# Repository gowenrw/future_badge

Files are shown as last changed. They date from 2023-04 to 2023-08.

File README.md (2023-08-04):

# future_badge

Future Badge Artifacts

This is a DEFCON Indie badge created for DC31.

This is where all the files for the Future Badge will be stored.

This includes code and art and cad and fab files.  All the things.

## File Structure

This is the file structure of this repository

* [/](/README.md) - YOU ARE HERE
* [/art/](./art/) - Artwork and other graphics created by this project
  * [/art/inspiration/](./art/inspiration/) - Art and graphics pulled from other sources used as inspiration for this project
  * [/art/fonts/](./art/fonts/) - Fonts used in art and graphics
* [/code/](./code/) - All project related Code / Firmware
* [/docs/](./docs/) - Documentation created by this project including web pages
* [/eda/](./eda/) - Electronic Design Automation files (i.e. KiCad)
  * [/eda/future_badge/](./eda/future_badge/) - KiCad 6.x project folder for the future_badge PCB
* [/reference_parts/](./reference_parts/) - Documentation pulled from other sources related to components
* [/README.md](/README.md) - This File
* [/LICENSE](/LICENSE) - Currently set to MIT

Note: the reference_parts directory is a link to a submodule repository.
To add it use the following cmd after cloning this:
```
git submodule add https://github.com/gowenrw/reference_parts reference_parts
```
This will make a link to the current commit of that repo.
To update it to a newer commit after its been added use this cmd:
```
git submodule update --init --recursive
```

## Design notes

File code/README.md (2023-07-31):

# Code

This is where all the project related Code / Firmware is located

# File Structure

This is the file structure of this repository

* [/](/README.md) - Home
* [/code/](/code/) - YOU ARE HERE

# Arduino IDE/CLI

The code presented here is mostly Arduino code.

In order to use this code and push new code to the ESP32 on the badge we recommend using the Arduino IDE/CLI software.
This can be downloaded for various platforms at [arduino.cc](https://www.arduino.cc/en/software).

The Arduino IDE UI will require some manual configuration to work with the badge ESP32 and our code.

The Arduino CLI can be used instead and allows for scripting much of the initial setup and use of whichever IDE you like (in my case I use VSCode).

# Arduino Versions

These are the Arduino IDE and CLI versions we have tested the code with:

* Arduino IDE v 2.1.1
  * [Windows MSI DL Link](https://downloads.arduino.cc/arduino-ide/arduino-ide_2.1.1_Windows_64bit.msi)
  * [Linux 64bit AppImage](https://downloads.arduino.cc/arduino-ide/arduino-ide_2.1.1_Linux_64bit.AppImage)
  * [Installation Instructions](https://docs.arduino.cc/software/ide-v2/tutorials/getting-started/ide-v2-downloading-and-installing)
* Arduino CLI v 0.32.3
  * [Windows MSI DL Link](https://github.com/arduino/arduino-cli/releases/download/0.32.3/arduino-cli_0.32.3_Windows_64bit.msi)
  * [Linux 64bit Tarball Link](https://github.com/arduino/arduino-cli/releases/download/0.32.3/arduino-cli_0.32.3_Linux_64bit.tar.gz)
  * [Installation Instructions](https://arduino.github.io/arduino-cli/0.32/installation/)

# Quickstart

If you want to jump right in and start compiling and uploading code using the Arduino CLI and the scripts provided then checkout the [QUICKSTART page](QUICKSTART.md).

# Arduino IDE setup and use

Some additional setup is required to use the Arduino IDE with the ESP32 on the badge:

* Add the ESP32 boards manager URL in preferences
  * Under File->Preferences find the "Additional boards manager URLs" section and add the following
  * https://espressif.github.io/arduino-esp32/package_esp32_index.json
  * Then click OK and close the IDE.  When it is reopened it wil download the ESP32 board definitions.
* Select the board "ESP32 Dev Module"
  * You need to select a board to associate with the code even if that board is not connected
  * In the "Select Board" dropdown, choose "ESP32 Dev Module" from the list
  * The first time you do this it may download some addiotional software.
* Connect the ESP32 via USB cable and select the COM port if it is not autodetected
  * In most cases it should autodetect the port
  * Sometimes on first connect you need to help it by going to Tools->Port and choosing the port
* This code exceeds the normal partition size so make sure you select the Minimal SPIFFS Partition type
  * This setting can be found under Tools -> Partition Scheme
* This code uses the AdaFruit NeoPixel library which needs to be installed
  * The library can be installed via the Arduino IDE library manager or manually
  * Installation instructions can be found at [the adafruit neopixel github page](https://github.com/adafruit/Adafruit_NeoPixel)

Once the Arduino IDE environment has been set up you can simply open one of the sketches here, make whatever changes you like, then compile and upload the code to the badge.

# Arduino CLI

In an effort to bring portability to the code here (since this is lacking in the Arduino 2.x IDE) we will be providing a local configuration file for the Arduino CLI and scripts to make use of it.

While we cannot ensure this will work on all systems, the files provided should at a minimum help you configure your local environment.

## Using the CLI Local Config

The arduino cli will use a global default config if a config file is not specified.

A local config file is provided named ```arduino-cli.yml``` which uses relative path references for the data and staging and build and user area that Arduino CLI should use.

These directories are local to the repository code directory and the CLI will install all its needed files here instead of in the various places it usually defualts to on differnt systems.

While this might duplicate many files on your system if they are already installed in default locations, it provides a consistent cross platform way of knowing exactly what libraries, headers, etc., that Arduino will use in the compilation of your code.

NOTE that the .gitignore for this repository has been set up to ignore the local directories used to store the core and library files to prevent these files from accidentally getting uploaded to github.

To use the Arduino CLI with this local config file simply add the ```--config-file arduino-cli.yml``` argument to each CLI command.

For example, the command below uses the local config file and will dump the current config to the screen
```
arduino-cli --config-file arduino-cli.yml config dump
```

## Setup for CLI

There are a few things that need to be done to setup the Arduino CLI for use with the badge ESP32 and our code.

The ESP32 board core files must be loaded as well as any libraries the code will use.

To simplify this setup we have created setup bash script named ```cli-setup.sh``` that can be run on Linux and Windows (via Git Bash for Windows).

To perform the CLI setup via the script execute it in the code directory
```
bash ./cli-setup.sh
```

This script will save any std_out and std_err output to a file named ```arduino_cli_setup.log``` which you can review if you are having issues.

To perform the CLI setup manually without this script you can use the commands outlined below.

### Installing the ESP32 board core for CLI

Since the config is specifying a third party core for the ESP32 we need to pull an initial index from it.  This search command will pull that index.
```
arduino-cli --config-file arduino-cli.yml core search esp32
```

Next we need to install the ESP32 board core files using this command.
```
arduino-cli --config-file arduino-cli.yml core install esp32:esp32
```

If the ESP32 board core files were already installed the above will simply say already installed.

To update the core file indexs to check for newer versions of previously installed cores, use the following command
```
arduino-cli --config-file arduino-cli.yml core update-index
```

To upgrade any previously installed cores use the following command
```
arduino-cli --config-file arduino-cli.yml core upgrade
```

### Installing the Neopixel Library

This code uses the AdaFruit NeoPixel library which needs to be installed

If this is the first time we are installing a library we will need the indexes so this search command will get them
```
arduino-cli --config-file arduino-cli.yml lib search 'Adafruit NeoPixel'
```

Next we need to install the Adafruit NeoPixel library files with this command
```
arduino-cli --config-file arduino-cli.yml lib install 'Adafruit NeoPixel'
```

If the Adafruit NeoPixel library files were already installed the above will simply say already installed.

To upgrade a previously installed version of this library use the following command
```
arduino-cli --config-file arduino-cli.yml lib upgrade 'Adafruit NeoPixel'
```

### Installing Other Libraries

In addition to the Neopixel Library above the CTF portion of our code requires a few more libraries.

These should be installed using the same steps as above.

This is the list of additional libraries needed

* "AsyncTCP"
* "ESPAsyncWebSrv"
* "DNSServer"

## Connect badge ESP32 board via CLI

The following command will dump a list of all available board cores installed
```
arduino-cli --config-file arduino-cli.yml board listall
```

Make sure the ESP32 we are using on the badge is in that list
```
  ESP32 Dev Module                 esp32:esp32:esp32
```

If it is not then retry the CLI setup to install the core files.

Next we will connect the badge ESP32 to our machine using a USB C cable
and check if the CLI can see it.

The following command will list all the connected boards the CLI sees
```
arduino-cli --config-file arduino-cli.yml board list
```

This will show the detected COM port and board type (which may be Unknown)
```
  Port Protocol Type                Board Name FQBN Core
  COM4 serial   Serial Port (USB)   Unknown
```

Don't worry if the board FQBN shows up as Unknown since we can set that

Take note of the COM port since we will need that to communicate with it later

## Compile code via CLI

At this point we should be ready to compile and upload code to the badge ESP32 board.

In the following examples we will be referencing the sketch ```future_badge_rev02``` code so you will need to change this for whichever sketch you wish to use.

The following command will compile the named sketch for use with our board fqbn
```
arduino-cli --config-file arduino-cli.yml compile --fqbn esp32:esp32:esp32 --build-path _build --export-binaries future_badge_rev02 --build-property build.partitions=min_spiffs --build-property upload.maximum_size=1966080
```

The arg ```--build-path _build``` is optional to have it put all build artifacts here instead of temp for ease of troubleshooting.

The arg ```--export-binaries``` will save the final binary files into ```<sketch_name>/build/<fqbn>/``` for use by upload.

The build property args ```--build-property build.partitions=min_spiffs --build-property upload.maximum_size=1966080``` make sure that the partition size and upload size are set properly.
Our code is THIC and wont fit in the default partition size.

When the CLI compile is run it should show you compile stats and/or errors similar to this
```
  Sketch uses 1827197 bytes (92%) of program storage space. Maximum is 1966080 bytes.
  Global variables use 48884 bytes (14%) of dynamic memory, leaving 278796 bytes for local variables.
  Maximum is 327680 bytes.
  Used library        Version Path
  Adafruit NeoPixel   1.11.0  .\code\libraries\Adafruit_NeoPixel
  WiFi                2.0.0   .\code\_data\packages\esp32\hardware\esp32\2.0.11\libraries\WiFi
  future_badge_ctf_r2 1.2.0   .\code\libraries\future_badge_ctf_r2
  AsyncTCP            1.1.4   .\code\libraries\AsyncTCP
  DNSServer           2.0.0   .\code\_data\packages\esp32\hardware\esp32\2.0.11\libraries\DNSServer
  ESPAsyncWebSrv      1.2.6   .\code\libraries\ESPAsyncWebSrv
  FS                  2.0.0   .\code\_data\packages\esp32\hardware\esp32\2.0.11\libraries\FS
  Used platform Version Path
  esp32:esp32   2.0.11  .\code\_data\packages\esp32\hardware\esp32\2.0.11
```

### Script to Compile code via CLI

To simplify the above we have created a bash script named ```cli-compile.sh``` that takes a single command line argument of the sketch name.

To perform the compile via the script execute it in the code directory
```
bash ./cli-compile.sh future_badge_rev02
```

## Upload code via CLI

Now we are ready to upload the binary we compiled to the badge ESP32 board.

Note that the binary file needed is saved to ```<sketch_name>/build/<fqbn>/``` and will be named ```<sketch_name>.ino.bin```
The code we have written here may include binaries which can be used without compiling and if you make changes and compile then these files should be overwritten.

The following command will upload the named sketch binary to the badge
```
arduino-cli --config-file arduino-cli.yml upload -p COM4 --fqbn esp32:esp32:esp32 --input-file future_badge_rev02/build/esp32.esp32.esp32/future_badge_rev02.ino.bin
```

NOTE: Saving the compiled binary in a defined place and uploading from an input file allows for quickly changing between different code without the need to compile each again.

It should show you upload stats and/or errors
```
  esptool.py v4.5.1
  Serial port COM4
  Connecting....
  Chip is ESP32-D0WD-V3 (revision v3.0)
  Features: WiFi, BT, Dual Core, 240MHz, VRef calibration in efuse, Coding Scheme None
  Crystal is 40MHz
  MAC: a8:42:e3:47:f0:50
  Uploading stub...
  Running stub...
  Stub running...
  Changing baud rate to 921600
  Changed.
  Configuring flash size...
  Flash will be erased from 0x00001000 to 0x00005fff...
  ...
  Compressed 18960 bytes to 13073...
  Writing at 0x00001000... (100 %)
  Wrote 18960 bytes (13073 compressed) at 0x00001000 in 0.3 seconds (effective 538.9 kbit/s)...
  Hash of data verified.
  ...
  Compressed 732656 bytes to 475614...
  Writing at 0x00010000... (3 %)
  Writing at 0x0001c1bd... (6 %)
  ...
  Writing at 0x000bcec0... (96 %)
  Writing at 0x000c2b72... (100 %)
  Wrote 732656 bytes (475614 compressed) at 0x00010000 in 6.3 seconds (effective 925.8 kbit/s)...
  Hash of data verified.
  Leaving...
  Hard resetting via RTS pin...
```

### Script to Upload code via CLI

To simplify the above we have created a bash script named ```cli-upload.sh``` that takes two command line arguments of the sketch name and serial port.

To perform the compile via the script execute it in the code directory
```
bash ./cli-upload.sh future_badge_rev02 COM4
```

## Monitor Serial Output

To monitor the serial output you can use the arduino-cli or your favorite serial app.

The following command will list all the connected boards so you can get the serial port
```
arduino-cli --config-file arduino-cli.yml board list
```

The arduino-cli monitor command with serial port (from above) and baud config can be used like this:
```
arduino-cli monitor --port COM4 --config baudrate=115200
```

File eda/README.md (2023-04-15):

# Electronic Design Automation

This is where all the Electronic Design Automation files for the PCB(s) will be stored.
The EDA used is KiCad 6.x unless otherwise specified.

## File Structure

This is the file structure of this repository

* [/](/README.md) - Home
* [/eda](/eda/) - YOU ARE HERE
  * /eda/<eda_project>/ - KiCad project folder for the named project PCB(s)
    * ./3d_models/ - This directory contains footprint 3d model files
    * ./gerber/ - This directory contains gerber formatted files for manufacturing
    * ./lib_fp/ - This directory contains footprint module directories
    * ./lib_sh/ - This directory contains schematic library files
    * ./snapshots/ - This directory contains prints of schematic / cad files and images of preview / final product

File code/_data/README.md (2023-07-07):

# _data

This diretory is used to store arduino cli created files.

This file ensures the creation of the directory locally.

The gitignore should prevent any other files here getting sent to the repo.

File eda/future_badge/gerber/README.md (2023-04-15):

# gerber

This directory is for the gerber formatted files to be sent to manufacturing

Subdirectories named by date in YYYY-MM-DD format contain the gerber files generated on that date.

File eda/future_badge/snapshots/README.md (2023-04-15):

# snapshots

This directory contains prints of schematic / cad files and images of preview / final product

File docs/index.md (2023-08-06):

---
layout: default
---

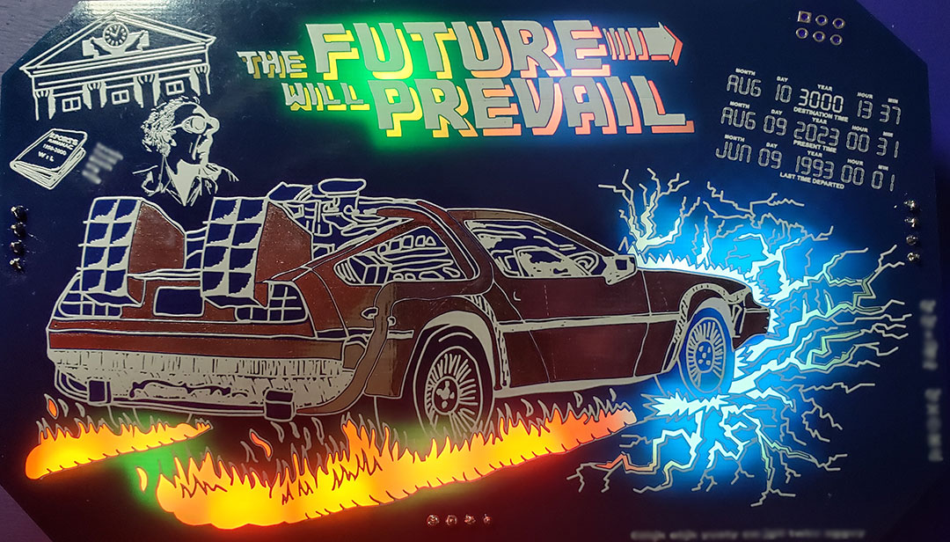
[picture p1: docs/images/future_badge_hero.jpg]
future badge hero


# Welcome

Welcome to the future badge website/repository.

This is where you will find all the details and files and instructions related to my DC31 future badge #badgelife.

The idea for this badge came from the DEFCON 31 theme: "The Future Will Prevail".
This theme made me think of the Back to the Future movies and the famous time traveling DeLorean.

This badge is mostly being provided as a DIY solder kit with a small quantity being provided fully assembled.
If you are looking for instructions on how to assemble the kit then you have come to the right place.

I hope that everyone who gets one of these badges enjoys it.  It was made with love for everyone in the community to enjoy.  And as with all my badges, it is all open hardware/software with all files provided in this repository.  So, if you didn't have a chance to get one of these kits at the con you can always make your own.

-- [@alt_bier](https://twitter.com/alt_bier)  - [My Contact Info](https://gowen.net/about)

---

# Sponsors

I want to thank all of our sponsors from the Indiegogo campaign that made this badge possible.

[Click this link to see the sponsor list.](future_badge_sponsors.md)

# Kit Assembly

Assembly Instructions for the Future Badge kit can be found here: [Badge Assembly](future_badge_assembly.md)

An assembly walkthrough video can be found here:
[Future Badge Soldering Walk-Through Video](https://youtu.be/ozqXjqQztUM)

# Details

As stated in the welcome, the idea for this badge came from the DEFCON 31 theme: "The Future Will Prevail".
This theme made me think of the Back to the Future movies and the famous time traveling DeLorean.
Having done a car on a previous badge (Godzilla vs Bladerunner) I saw this as an opportunity to improve on that by making the car capacitive touch sensitive and the fact that the DeLorean in the BTTF movies was metalic silver made this a perfet fit.

In keeping with the theme I wanted to make the badge look like a BTTF movie poster and shape it like a movie ticket.
I think the final design was sucessful on both accounts.

I made a design choice to use back lit solder mask voids and two PCBs to sandwich the components hiding them and highlighting the art.
Having seen other groups do these things so sucessfully in the past (looking at you DC540!) I wanted to tackle this and I think it turned out great.

Since I had not used an ESP on a badge yet I decided to use the ESP32 on this one.
One of the cool things about the ESP32 is the built in wireless.
So, we are planning on making use of that with an embedded CTF challenge (if we can get the code working in time LOL)

Speaking of challenges, this badge includes some crypto challenges right on the front silkscreen art.
Nothing too difficult, but a fun feature that will be used in the code based challenge.

In keeping with my goal of making the badge code accessible to people I decided to use Arduino code for this badge.
This presented its own set of challenges as Arduino code it not nativley very mobile and requires lots of local config to match an environment.
I came up with a fix for this by using the Arduino CLI instead of the IDE and using a locally provided config file and scripts for setup, compile, and upload.
See the code readme file for details.

The final design choice that I do have some regrets about is the use of a 9V battery.
I thought it would be cool since many Arduino and other dev board projects use a 9V but I don't recall ever seeing one on a badge.
I know now why 9V batteries are not used on badges.
I was warned to change it but was too far along the development path to do so.
My first prototype board only lasted about 2 hours on a 9V with the wifi off.
Thanks to true from the Whiskey Pirate Crew I was able to get a voltage regulator circuit added that now makes the badge run for 7 to 8 hours on a 9V.
Still not ideal and I'll be providing two 9V batteries in each kit and have lots of spares at defcon to compensate.
But it looks cool right?

# Code

The code is detailed in the github repo which can be found here: [Code Documentation](https://github.com/gowenrw/future_badge/blob/main/code/README.md)

The CTF challenge is a compiled library so you won't gain any hints there.
That source code will be released after defcon.

The rest of the code is open to see and modify as you will.

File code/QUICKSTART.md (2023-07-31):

# Code Quickstart

Notes:

* You will need Arduino CLI Installed and a Bash shell (on Windows Git Bash is provided by Git for Windows)
* The CTF code is a precompiled library so you cant change that for now, source to be released after defcon
* The current code that is loaded on the badge is the sketch named ```future_badge_rev02```

## Setting up Arduino CLI environment

Follow these steps:

* Change directory to the code directory if you arent already there
* Run the following command preceding it with ```bash``` if needed by your OS
  * ```./cli-setup.sh```
* If it completes without errors then setup is complete
  * If you have errors then refer to the main README doc or script file to try the steps manually

## Compiling Code

Once you have made whatever changes you wanted to the code here is how we compile it.

* Change directory to the code directory if you arent already there
* Run the following command preceding it with ```bash``` if needed by your OS changing the sketch name if needed
  * ```./cli-compile.sh future_badge_rev02```
* If it completes without errors then the compile is complete
  * If you have errors then read what they are and make the appropriate changes to your code

## Upload Code

Once the code has been compiled we can upload it to the badge.

Follow these steps:

* Change directory to the code directory if you arent already there
* Run the following command
  * ```arduino-cli --config-file arduino-cli.yml board list```
* Take note of the serial port name of the connected board 
* Run the following command preceding it with ```bash``` if needed and changing the serial port to above
  * ```./cli-upload.sh future_badge_rev02 COM6```

## Serial Monitor

Once the code has been uploaded you can use the serial monitor to look for any text the code is sending.

* Run the following command changing the serial port to what board list showed above
  * ```arduino-cli monitor --port COM6 --config baudrate=115200```

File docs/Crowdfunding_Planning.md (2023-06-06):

# Crowdfunding Planning

Notes about Crowdfunding planning.

## Which Platform

Kickstarter vs Indigogo

Both have similar features.  However, kickstarter seems to have several built in delays.

Both require funding identity verification but kickstarter has a 1-3 business day review period before launch.

Going to set up on both platforms and fastest to be ready to launch will win.

Update: Indigogo won!

https://igg.me/at/future-badge

## Basics

* Campaign Title
  * Future Badge: Wearable Art DEFCON #Badgelife
* Campaign Tagline
  * Future Badge is a wearable piece of electronic art manufactured into a badge themed for DEFCON 31.
* Campaign Card Image
  * Created a 640x640 image
  * [future_badge_campaign_card-1](art/future_badge_campaign_card-1.jpg)
* Images/Video
  * Initial images of concept art and kicad
  * Link to the future badge diaries youtube playlist (Watch progress being made week by week)
* Campaign
  * Submit on Saturday 6/3
  * Launch prior to June DHA if possible
  * Campaign will last 30 days closing first week of July.

## Funding

* Goal is $5000
* Pricing
  * $10 - No-Limit - Buy us a Beverage (No Reward)
  * $60 - Limit 120 - Future Badge Kit
  * $100 - Limit 30 - Future Badge Assembled
* Streach Goal is $7000
  * If the streach goal is met then an SAO addon badge will be created
  * This SAO will be included as a reward for the $60 and $100 support tiers

## Rewards

* The $10 support tier
  * Just a tip with no reward
* The $60 support tier
  * A ticket to pick up a Future Badge Kit (DIY soldering and assembly required)
  * If streach goal met then this ticket will also include an SAO addon
  * Sponsors at this level will receive a digital ticket which entitles them to pick up a Future Badge Kit at one of the badge distributions.
  * The Future Badge Kit is a DIY kit with soldering and assembly required using the components and instructions provided.
  * The Future Badge is a wearable piece of electronic art manufactured in the style of a conference badge themed for the Defcon 31 conference.
  * The badge features an ESP32 controller, at least 16 LEDs including 4 neopixels, capacitive touch, awesome artwork, hackable Arduino code, custom lanyard, and more.
  * Sponsors are responsible for picking up their product at one of the distribution locations/dates/times listed.
* The $100 support tier
  * A ticket to pick up a Fully Assembled Future Badge (No assembly required)
  * If streach goal met then this ticket will also include an SAO addon
  * Sponsors at this level will receive a digital ticket which entitles them to pick up a Fully Assembled Future Badge at one of the badge distributions.
  * The Fully Assembled Future Badge is ready to wear with no assembly required.
  * The Future Badge is a wearable piece of electronic art manufactured in the style of a conference badge themed for the Defcon 31 conference.
  * The badge features an ESP32 controller, at least 16 LEDs including 4 neopixels, capacitive touch, awesome artwork, hackable Arduino code, custom lanyard, and more.
  * Sponsors are responsible for picking up their product at one of the distribution locations/dates/times listed.

## Story

* Detailed project Description
```
  Future Badge by @alt_bier and team
  The Future Badge is a wearable piece of electronic art manufactured in the style of a conference badge themed for the DEFCON 31 conference.   This style of wearable art is known as #Badgelife by collectors.

  Product Details
  This badge will have the following features: an ESP32 controller, at least 14 LEDs including 4 NeoPixels, capacitive touch, awesome artwork, hackable Arduino code, two interconnected PCBs, custom lanyard, and more.

  The DEFCON 31 conference will take place in Las Vegas, NV from Aug 9-13 2023 and has a theme of "The Future Will Prevail" which is what we based this badge on.  You can find out more about this conference here https://defcon.org/

  This badge will have a Back to the Future look complete with a DeLorean transitioning into time (flames and lightning effects) presented in a unique dual PCB design that showcases the art on the top PCB hiding the electronics in a secondary attached back PCB.

  There will be puzzles included on the badge to be solved including a crypto challenge (code breaking, not coin mining!) and something that makes use of the embedded wireless.

  Hackable
  The badge will be programmed with Arduino code making it easily hackable by anyone wishing to reprogram it to do different things.

  The ESP32 on the badge has an embedded wireless controller that can be programmed for a variety of uses beyond the capture the flag puzzle we are planning to include.

  Collectable
  As with most #Badgelife creations this badge will be a collectable.  Given the limited quantity and demand these badges can retain their value and more years later.

  This will be @alt_bier's 9th #Badgelife creation.  But, this will be the first time you can pledge to sponsor one of these creations and guarantee you get one (all past @alt_bier #Badgelife was sold in person).  You can find links to his past creations here https://altbier.us/

  What We Need
  We have started the design work for this project and are progressing quickly to production.

  We need to raise funds in order to purchase all the components and have the PCB's manufactured.

  We need your help to make this badge a reality!

  Progress
  You can see the progress being made by viewing the weekly Twitch live streamed design sessions here https://www.twitch.tv/alt_bier_hacker

  You can see the complete history of this project from concept to current with the past stream sessions available for viewing in the Future Badge Diary playlist on YouTube here https://www.youtube.com/@alt_bier_hacker

  What Sponsors Will Get
  Sponsors who pledge for any of the reward tiers will be afforded the opportunity to opt-in to having their name or handle listed on the badge project website as a sponsor of the badge. 

  Sponsors who pledge for one of the badge reward tiers will receive an electronic ticket that can be used to pick up their badge at on of the distributions points.

  There are two products being offered as rewards to badge tier sponsors based on the sponsorship level.  The first is a Future Badge Kit that will require DIY soldering and assembly.  The second is a fully assembled ready to wear Future Badge.

  It is a sponsors responsibility to pick up their reward badge at a distribution point.  Any unclaimed badges after the last distribution will be considered a starving hacker donation and given away.  There will be no shipping.

  Sponsor Reward Distribution
  There will be a minimum of Five badge distributions, two in the DFW area prior to DEFCON and three in Las Vegas during DEFCON.  We may add additional distributions if needed.  

  The locations, dates and times of the initial badge distributions are below with any changes or additions being announced and kept up to date to allow sponsors to plan their pickup.

  DFW Area Distributions

  Wednesday Aug 2nd 7PM-9PM
    DHA (Dallas Hackers Association) August Meetup at Family Karaoke
    11433 Goodnight Ln · Dallas, TX
  Saturday Aug 5th 12PM-2PM
    Plano Wal-Mart parking lot badge drop
    6001 Central Expy, Plano, TX 75023

  DEFCON Las Vegas Distributions

  Wednesday Aug 9th 10PM-12AM
    Line-Con Badge Drop at Caesars Forum - find us in the DEFCON line
    Caesars Forum, 3911 Koval Lane, Las Vegas, NV, 89109
  Thursday Aug 10th 4PM-6PM
    Happy Hour Badge Drop at 3535 Coctail Bar in the LINQ lobby
    LINQ, Las Vegas, NV 89109
  Friday Aug 11th 11AM-1PM
    Hardware Hacking Village Badge Drop in the DEFCON HHV area in Flamingo
    Flamingo, Las Vegas, NV 89109
```

* Risks and Challenges
  * The main risk with designing a product like this is that the circuit does not perform as intended.  We intend to mitigate this risk with a small run of prototypes to fully test and tweak the design prior to the larger production manufacturing run.

* FAQ
  * Can I have my reward shipped If I cannot make it to one of the sponsor reward distributions?
    * No. We are not staffed to handle shipping in quantity.  It is the sponsors responsibility to pick up their reward badge at one of the distributions.  And reward badges not picked up after the last distribution will be considered forfeit by the sponsors and these badges will be given away to random DEFCON attendees.
  * What can the badge do?
    * The badge will perform various light displays that can be changed using the capacitive touch panels on the car.  It will also make use of the onboard WiFi for a puzzle in some way to be determined.  It will be programmed using Arduino code and thus can be reprogrammed to do whatever you would like within the limitations of the hardware.

## Plan

* Product Stage
  * Concept
    * Completed
  * Prototype
    * In Progress
  * Production
    * TBD
  * Shipping
    * TBD

* Milestones
  * Prototype
  * Testing & Design Updates
  * Production Run
  * Assembly
  * Packaging
  * Distribution

* Communication Plan
  * Email Communication on major milestones
  * Weekly video progress (twitch/youtube)

## People

* Badge Team and roles

## Payment

* Funding destination

## DFW Area Distributions

* Wednesday Aug 2nd 7PM-9PM
  * DHA (Dallas Hackers Association) August Meetup at Family Karaoke
  * 11433 Goodnight Ln · Dallas, TX
* Saturday Aug 5th 12PM-2PM
  * Plano Wal-Mart parking lot badge drop
  * 6001 Central Expy, Plano, TX 75023

## DEFCON Las Vegas Distributions

* Wednesday Aug 9th 10PM-12AM
  * Line-Con Badge Drop at Caesars Forum - find us in the DEFCON line
  * 3911 Koval Lane, Las Vegas, NV, 89109
* Thursday Aug 10th 4PM-6PM
  * Happy Hour Badge Drop at 3535 Coctail Bar in the LINQ lobby
  * LINQ, Las Vegas, NV 89109
* Friday Aug 11th 11AM-1PM
  * Hardware Hacking Village Badge Drop in the DEFCON HHV area in Flamingo
  * Flamingo, Las Vegas, NV 89109

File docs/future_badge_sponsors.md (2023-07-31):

---
layout: default
---

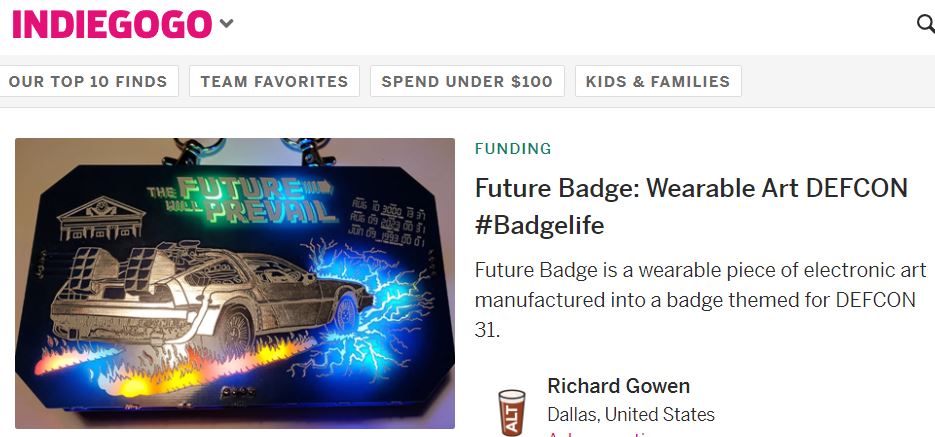
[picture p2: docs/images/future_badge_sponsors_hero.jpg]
future badge assembly hero


# Future Badge Sponsors

I want to thank all of our sponsors from the Indiegogo campaign that made this badge possible.

Without these sponsors I would not have been able to afford to make this badge given that I was unemployed when we started work on it.

We had a total of 93 people sponsor us by pledging to get 100 badges.

Not every sponsor from the crowd funding campaign will be listed as this was an opt-in choice.

## Sponsor List

This is the list of the people who opted-in to being listed as a sponsor

* ```Acetolyne```
* ```BigTaro```
* ```blancohak```
* ```CactusJack```
* ```dclaw```
* ```Dvir0s```
* ```Eric aka TechMedic76```
* ```Frosty Dirona```
* ```gdb```
* ```K4rm4```
* ```mnteye```
* ```NinjaLikesCheez```
* ```ReanimationXP```
* ```ReloadRtr```
* ```@rj_chap```
* ```@spike@infosec.exchange```
* ```__t0rn__```
* ```TruBluFan```
* ```virtsean```

## Home

[Return to Home Page](/)

---

[@alt_bier](https://twitter.com/alt_bier)  - [My Contact Info](https://gowen.net/about)

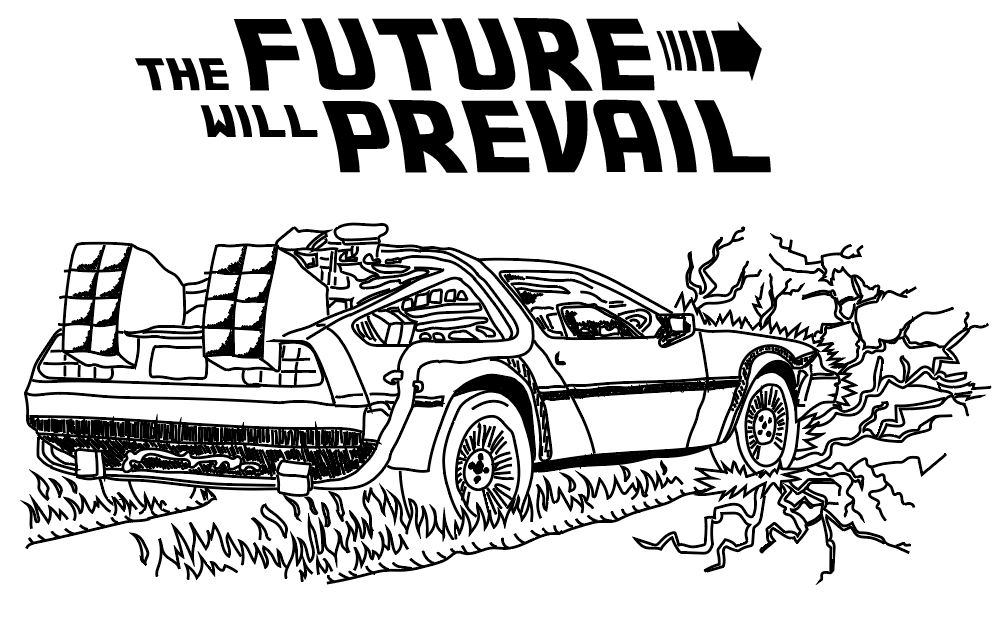
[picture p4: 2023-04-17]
art/Concept_draft.jpg

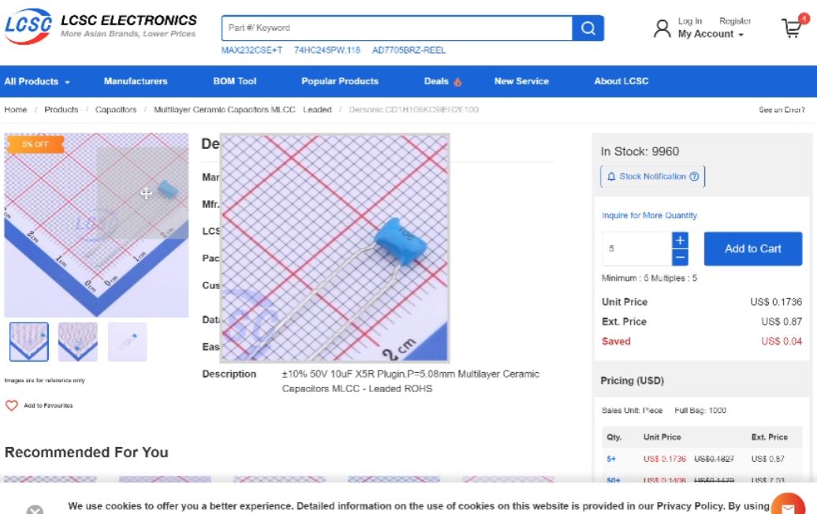
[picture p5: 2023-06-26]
docs/images/1Capture.JPG

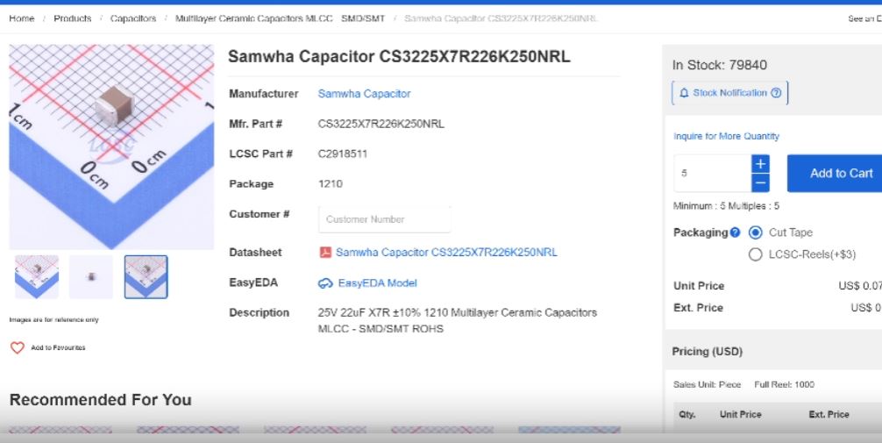
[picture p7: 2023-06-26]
docs/images/3Capture.JPG

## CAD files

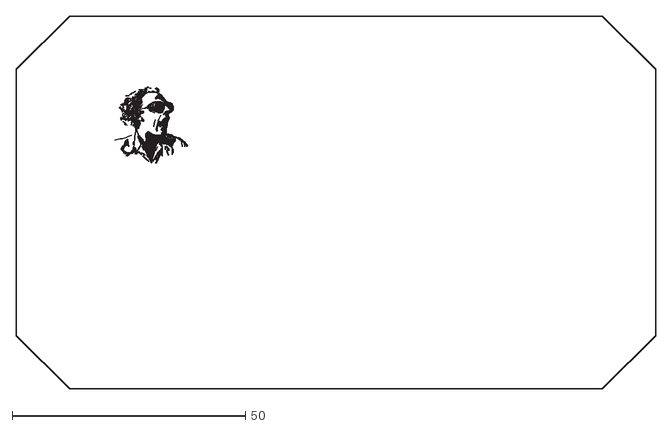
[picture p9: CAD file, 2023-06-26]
art/future_badge_art-2-frontsilk-docbrown-7-2.dxf
137.1 x 80.0

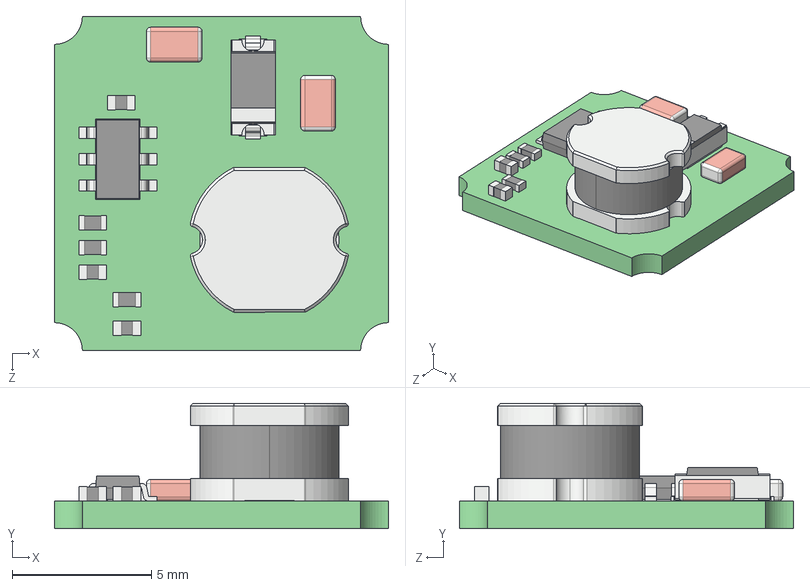
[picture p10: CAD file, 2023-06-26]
eda/future_badge/3d_models/CUI_PXO7803-500-M-TR.step
12.0 x 4.50 x 12.0 mm

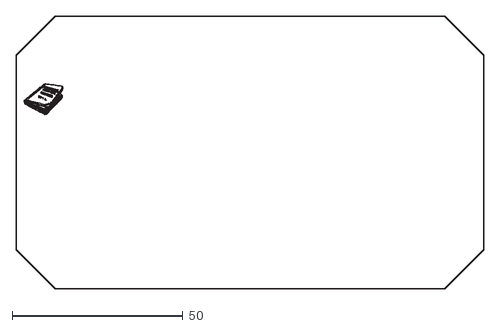
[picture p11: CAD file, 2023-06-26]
art/future_badge_art-2-frontsilk-book-7-2.dxf
137.1 x 80.0

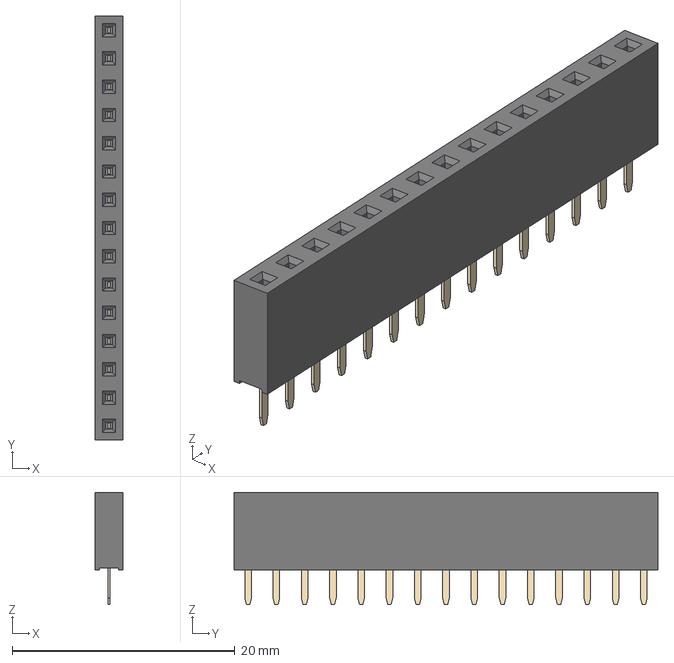
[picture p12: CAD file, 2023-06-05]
eda/future_badge/3d_models/PinSocket_1x15_P2.54mm_Vertical.step
2.54 x 38.1 x 10.1 mm

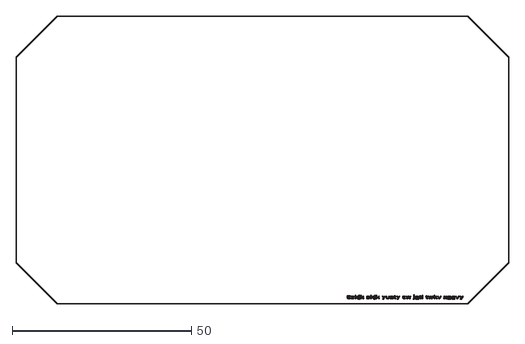
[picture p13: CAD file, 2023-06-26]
art/future_badge_art-2-frontsilk-c3-7-2.dxf
137.1 x 80.0

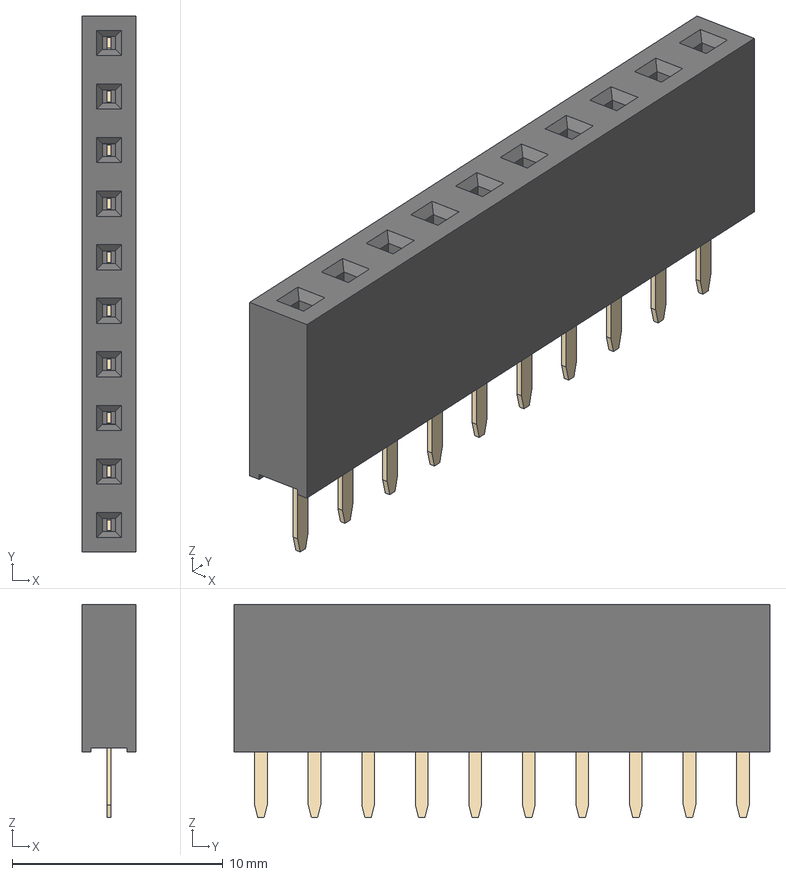
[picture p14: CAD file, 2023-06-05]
eda/future_badge/3d_models/PinSocket_1x10_P2.54mm_Vertical.step
2.54 x 25.4 x 10.1 mm

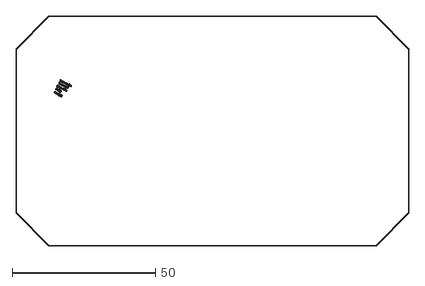
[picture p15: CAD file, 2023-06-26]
art/future_badge_art-2-frontsilk-c1-7-2.dxf
137.1 x 80.0

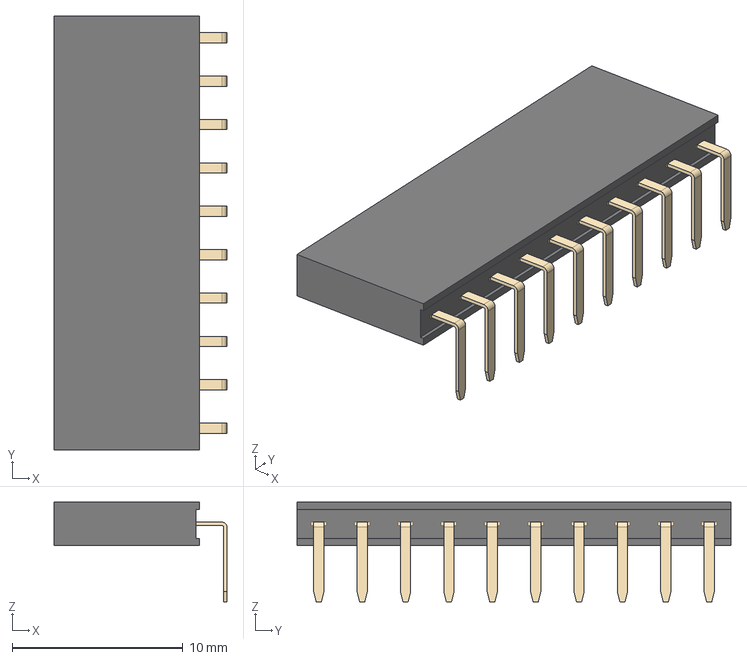
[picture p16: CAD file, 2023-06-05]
eda/future_badge/3d_models/PinSocket_1x10_P2.54mm_Horizontal.step
10.1 x 25.4 x 5.84 mm

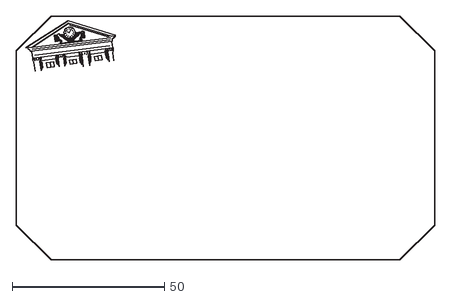
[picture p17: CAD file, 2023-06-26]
art/future_badge_art-2-frontsilk-clocktwr-7-2.dxf
137.1 x 80.0

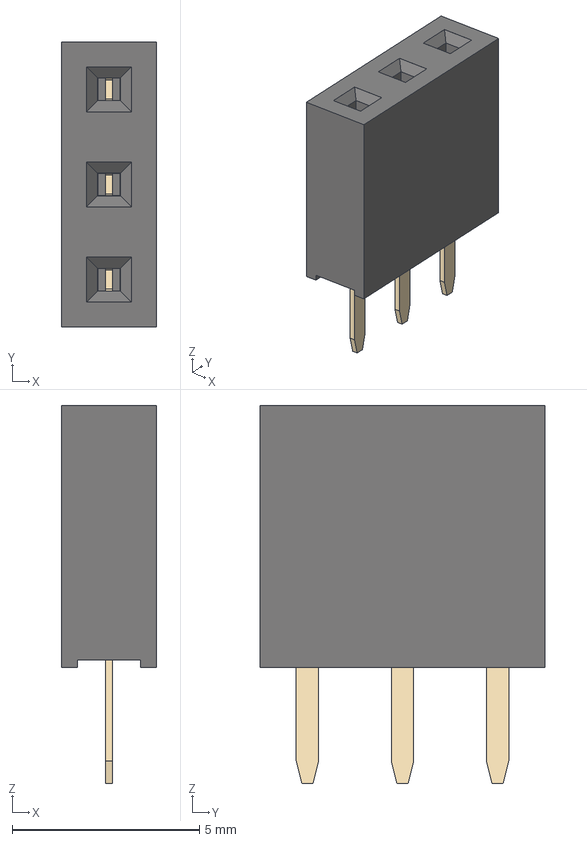
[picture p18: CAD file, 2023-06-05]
eda/future_badge/3d_models/PinSocket_1x03_P2.54mm_Vertical.step
2.54 x 7.62 x 10.1 mm

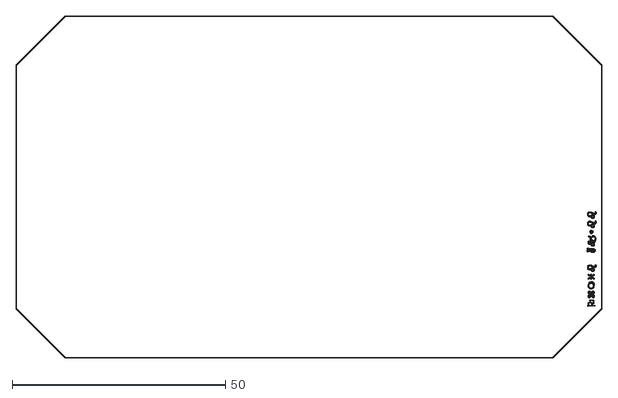
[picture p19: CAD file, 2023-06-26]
art/future_badge_art-2-frontsilk-c2-7-2.dxf
137.1 x 80.0

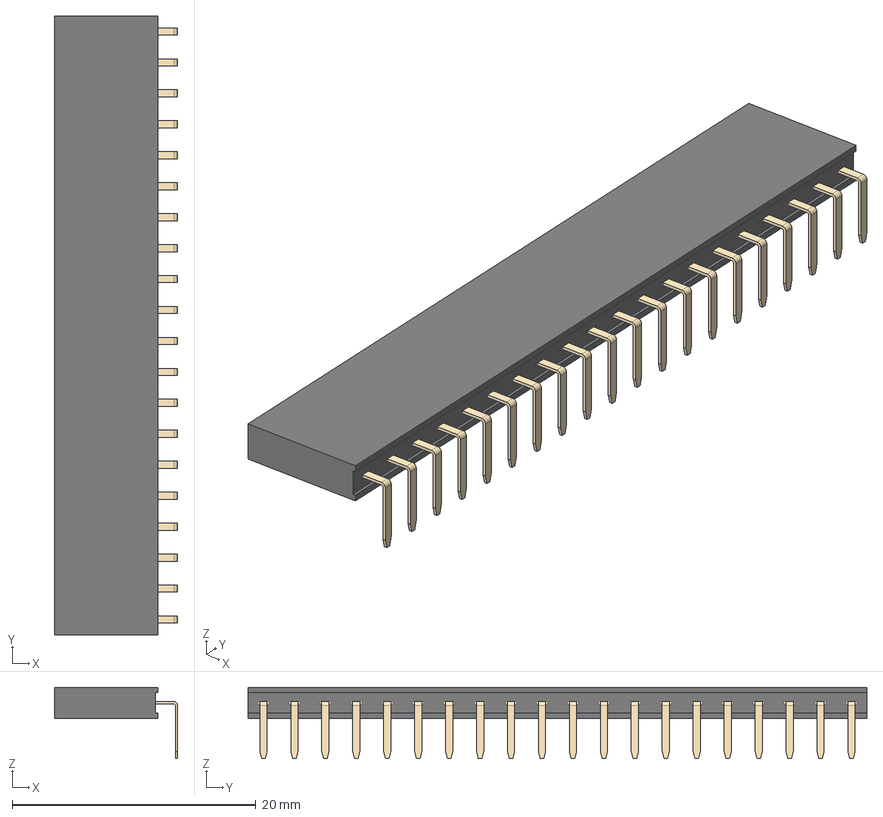
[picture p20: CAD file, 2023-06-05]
eda/future_badge/3d_models/PinSocket_1x20_P2.54mm_Horizontal.step
10.1 x 50.8 x 5.84 mm

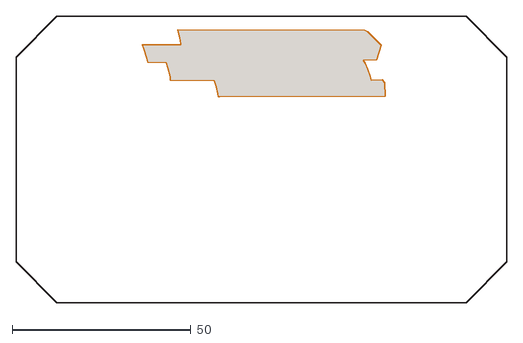
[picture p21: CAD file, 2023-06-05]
art/future_badge_art-2-backmask-title-7-2.dxf
137.1 x 80.0

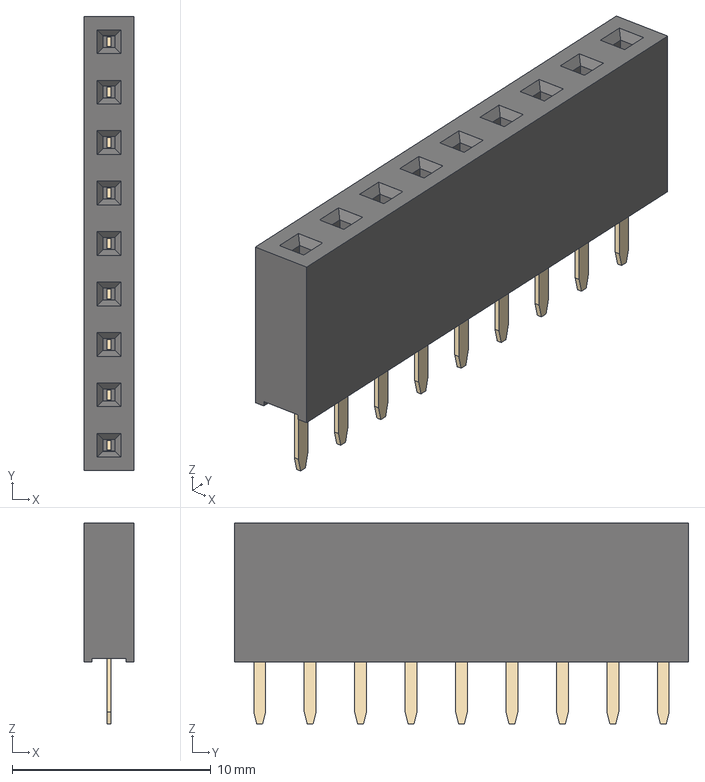
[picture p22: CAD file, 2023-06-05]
eda/future_badge/3d_models/PinSocket_1x09_P2.54mm_Vertical.step
2.54 x 22.9 x 10.1 mm

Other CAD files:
art/future_badge_art-2-backmask-lightning-7-2.dxf
eda/future_badge/3d_models/PinSocket_1x04_P2.54mm_Vertical.step
art/future_badge_art-2-frontmask-title-7-2.dxf
eda/future_badge/3d_models/PinSocket_1x07_P2.54mm_Vertical.step
art/future_badge_art-2-backmask-flames-7-2.dxf
art/future_badge_art-2-edgecuts-7-2.dxf
art/future_badge_art-2-frontcopper-delorean-7-2.dxf
art/future_badge_art-2-frontmask-delorean-7-2.dxf
art/future_badge_art-2-frontmask-flames-7-2.dxf
art/future_badge_art-2-frontmask-lightning-7-2.dxf
art/future_badge_art-2-frontsilk-notxt-7-2.dxf
art/future_badge_art-2-frontsilk-panel-txt-7-2.dxf
art/future_badge_art-2-frontsilk-title-txt-7-2.dxf
eda/future_badge/3d_models/BatteryHolder_2466_1xAAA.step
eda/future_badge/3d_models/BatteryHolder_2468_2xAAA.step
eda/future_badge/3d_models/Battery_Holder_3xAAA_Simple.step
eda/future_badge/3d_models/Battery_Holder_CR2032_BS-2-1.stp
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

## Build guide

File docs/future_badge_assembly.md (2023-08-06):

---
layout: default
---

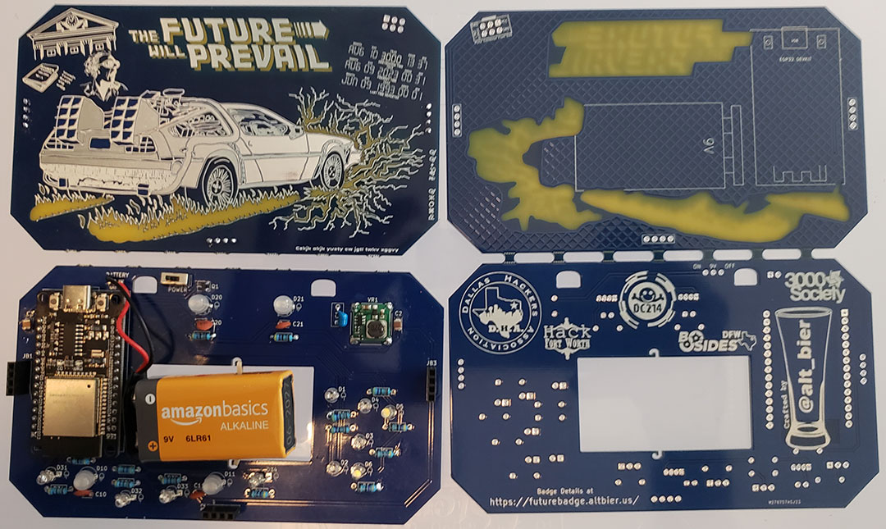
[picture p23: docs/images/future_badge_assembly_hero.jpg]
future badge assembly hero


# Future Badge Assembly Instructions

Here are the assembly instructions I put together for the future badge.

There is also a [Future Badge Soldering Walk-Through Video](https://youtu.be/ozqXjqQztUM) that you may find helpful.

## Badge Distribution Packages

The badges have been distributed in three different packages

* KIT - This is the standard kit that requires DIY soldering/assembly of all components (including 4 SMT)
* WMP - This is the "With Mounted Parts" kit that requires DIY soldering/assembly of all components EXCEPT the SMT components which have been pre-mounted on the PCB
* ASS - This is a Fully Assembled ready to wear badge

## Component List

This is the list of components that you should have available for the assembly

* Main Kit Bag (7x9in) Containing:
  * 1x PCB panel (which breaks apart for top/front and bottom/rear PCBs)
  * 1x Lanyand
  * 1x 9V Battery
  * 1x Sticker (Not Required for badge Assembly)
  * Small Component Bag (3x4in) Containing:
    * 1x ESP32 WROOM Development board
  * Large Component Bag (6x8in) Containing:
    * 1x Header Male Breakaway Strip with 1x40 Pins
    * 3x Header Female 1x4 Pins
    * 1x Header Female Keyed 2x3 Pins (Badge SAO connector)
    * 1x 9V Battery connector
    * 2x Rubber Band #8 size (1 req. 1 spare)
    * Medium Component Bag (4x6in) Containing:
      * 1x THT SS12D00 3-Pin SPDT Switch
      * 4x THT 100nF Ceramic Disc Capacitors
      * 1x THT 10uF 50V X5R 106 5.08mm Multi-Layer Ceramic Capacitor
      * 4x THT WS2812D RPIN 5mm 4-Pin Addressable LEDs
      * 4x THT Two Color (Red-Yellow) 3mm 3-Pin LEDs
      * 4x THT One Color (Blue) 3mm 2-pin Flat Top LEDs
      * 2x THT One Color (White) 3mm 2-pin Round Top LEDs
      * 14x THT 47 Ohm 6.2mm Metal Film Resistors
    * Small Component Bag (3x4in) Containing:
      * NOTE: The WMP kit has SMD components pre-assembled so this bag will not be present
      * 1x SMT CJ3139k 20V 0.66A PNP SOT-23 MOSFET Transistor
      * 1x SMT LMTOE78_03-0.5 12x12mm Step Down Power Regulator
      * 2x SMT 22uF 25V X7R 1210 Multi-Layer Ceramic Capacitor

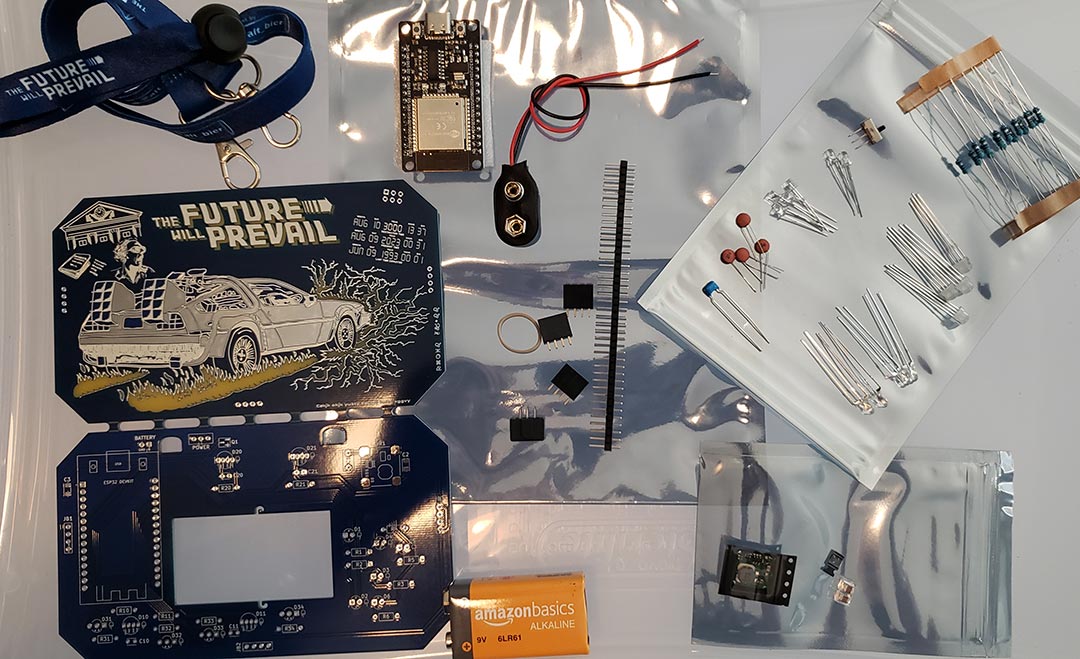
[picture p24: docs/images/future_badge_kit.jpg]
future badge kit


## Soldering Steps

These are the assembly steps that require soldering.
I have presented them in the order I recommend they be implemented for best results.

### Surface Mount

If you are working with the standard KIT then you will need to solder the surface mount components.
If you got the WMP kit (with mounted parts) then skip these steps.

* Solder the four SMDs (surface mount devices) first
  * These parts have extra large pads allowing for hand soldering with traditional iron and solder but solder paste with hotair/hotplate also works well
  * I start with the largest and progress to the smallest of these
    * VR1 - This voltage regulator is a large (12mmx12mm!) square component with pads on the 4 corners
      * Align VR1 using the silk drawing of it on the PCB and solder the 4 corners
    * C2 and C3 - These 22uF capacitors are in a chunky 1210 package and are non-polar (she goes both ways)
      * Place C2 and C3 onto the pads and solder the 2 ends of each
    * Q1 - This MOSFET transistor is a small SOT-23 package with 3 pins (2 on one side, 1 on other)
      * Align Q1 pins with pads and solder its 3 pins

### Through Hole

If you are working with the standard KIT or the WMP kit (with mounted parts) then you will need to solder the through hole components.

* Almost all components are on the bottom/rear PCB so we start with that one
  * The top/front PCB has only headers which will be done last
* Placement of the THT (through hole technology) components on the 
  * These components are placed on the front of the PCB where the component labels are and soldered on the back side of that PCB
* I start with the resistors since there are a lot of them and they are easy to do all at once
  * There are 14 47-Ohm resistors labeled R1-R6, R10-11, R20-21. and R31-34
  * Resistors are non-polar so they can be placed in either direction.
  * Place all the resistors into the PCB bending thier legs outward to hold them in place
  * Solder all 28 resistor connections (both ends of the 14 resistors)
  * When cooled cut the component legs off at the top of the solder joints (do not cut into the solder joint)
* Capacitors are next
  * C1 - This is a blue colored 5mm wide 2 pin 10uF MLCC non-polar capacitor
  * C10, C11, C20, C21 - These are tan colored 2.5mm wide 2 pin 100nF ceramic disc non-polar capacitors
  * Place all the capacitors in thier designated places on the PCB bending legs out to hold in place
  * Solder all the capacitor connections
  * When cooled cut the component legs off at the top of the solder joints (do not cut into the solder joint)
* The traditional one color 2 pin LEDs are easy but there are two types so be careful with placement
  * D1-D4 - These are 3mm 2-pin Clear FLAT TOP LEDs that emit BLUE light
  * D5-D6 - These are 3mm 2-pin Clear ROUND TOP LEDs that emit WHITE light
  * Place the LEDs in thier designated places on the PCB bending legs out to hold in place
  * Make sure to align the LEDs properly using the silk guide to place short leg in square hole
  * DO NOT force the LED down flush with the board, stop when you feel resistance
  * Solder all the LED connections
  * When cooled cut the component legs off at the top of the solder joints (do not cut into the solder joint)
* Two color 3 pin LEDs are easy to solder but need proper alignment for colors
  * D31-34 - These are 3mm 3-pin Clear LEDs that emit RED and/or Yellow light
  * Place the LEDs in thier designated places on the PCB bending legs out to hold in place
  * Make sure to align the LEDs properly using the silk guide to place short leg in square hole
  * DO NOT force the LED down flush with the board, stop when you feel resistance
  * Solder all the LED connections
  * When cooled cut the component legs off at the top of the solder joints (do not cut into the solder joint)
* Addressable neopixel LEDs are a bit more difficult to solder given the pins are close
  * D10-D11, D20-D21 - These are 5mm 4-pin frosted short hat LEDs that are addressable RGB neopixels
  * Place the LEDs in thier designated places on the PCB bending legs out to hold in place
  * Align the LEDs properly using the silk guide to place longest leg in VDD (middle hole next to square hole)
  * DO NOT force the LED down flush with the board, stop when you feel resistance
  * Solder all the LED connections
  * When cooled cut the component legs off at the top of the solder joints (do not cut into the solder joint)
* The ESP32 development board should be easy to solder
  * ESP32 DEVKIT - This is the 30 pin ESP32 WROOM development board
  * Place the ESP32 in its designated place on the PCB using the silk guide to align with usb toward top of PCB
  * Optionally you can keep the dev board raised off the PCB inserting only enough of the legs to allow soldering
    * This avoids the need to cut excess leg length off the back of the pcb later
  * Solder all the ESP32 connections
  * When cooled, if needed, cut excess leg length off at the top of solder joints (do not cut into the solder joint)
* Switch for battery power is next
  * The battery power switch is a 3-pin SPDT switch with a 3mm lever
  * This was designed to be placed on the front of the PCB like all the other components
    * This places the switch in between the two PCBs when the badge is assembled
    * Optionally the switch can be mounted on the other side to keep it on the back
    * Mounting on the back provides easier access but also has it rub against the wearer
  * Place the switch in its designated place on the PCB in either direction
  * Solder all the switch connections
  * When cooled, if needed, cut excess leg length off at the top of solder joints (do not cut into the solder joint)
* Female headers must maintain 90 degree angle to the PCB
  * JB1-3 - These are 4-pin 2.54mm Female headers
  * We will solder these headers one at a time to allow us to adjust angle
  * Place a header into the PCB and while holding it in place solder ONE pin
  * Check the alignment to make sure it is at a 90 degree angle from the PCB
  * If angle adjustment is needed heat up that one soldered pin and move angle as needed
  * Once the header is at the proper angle solder the remaining connections
  * Repeat this for the other two headers
* Battery connector is the last component on the bottom/rear PCB
  * The 9V battery connector comes with long lead wires that will need to be cut to size
  * Do not cut the wires too short, some excess wire is ok as it can be tucked under the ESP
  * Strip about 1/8th inch (3mm) of plastic off the ends of the lead wires
  * Twist the wire strands to allow them to easily insert into the holes, optionally Tin the lead wires
  * Place the lead wires into thier designated places on the PCB
    * Red wire is placed in square hole marked +
    * Black wire is placed in round hole marked GND
  * Solder the lead wires in place
* With the bottom/rear PCB complete we can proceed to the top/front PCB
* Male headers on the top/front PCB must align with the female headers on the bottom/rear PCB
  * Prepare three 4-pin Male headers by breaking them off the provided 40-pin breakaway strip
  * These 4-pin 2.54mm Male headers will be soldered on the front side of the top/front PCB
  * With the bottom/rear PCB component side up, place the male headers into the female headers on that PCB
  * Place the top/front PCB art side up onto the male headers in the appropriate holes on three sides
  * Solder the male headers to the top/front PCB
  * When cooled remove the top/front PCB with its male headers now attached from the bottom/rear PCB
* SAO connector is keyed and needs proper alignment
  * The SAO connector is a 2x3 pin Female Keyed header that must have the key aligned
  * This will be placed on the front of the PCB, soldered on the back where the silk labels are
  * The silk guide shows that the header key should be aligned toward the top edge of PCB
  * Solder all the SAO header connections

## Additional Assembly Steps

These are the additional assembly steps that do not require soldering.

### Separating the PCBs

Breaking apart the PCBs can be done at any point.
But, since you will only be working on one PCB at a time it may make sense to do this before soldering.

* Break apart the PCBs on the mouse bites
  * To provide an even break line placing one PCB on a hard surface (like a desk) and pushing down on the other PCB works well
  * Break off the mouse bites from the PCB(s) that they are still attached to
  * Mini pliers are helpful but not required
  * The rough edges can be filed or sanded down if a smooth edge is preferred

### Final Assembly

* Take one #8 rubber band and attach either end of it to the hooks in the center of bottom/back PCB
* Connect the top/front and bottom/back PCBs via the 4 pin headers on three sides

## Wear and Enjoy!

* With switch in off position attach 9V battery to battery connector
* Slide 9V battery between the rubber band and the top/front PCB
* Attach lanyard to provided holes on bottom/rear pcb
* Wear the badge and adjust lanyard length by pushing the button on the lanyard plastic ball
* Move the switch to the on position
* Enjoy!

## Home

[Return to Home Page](/)

---

[@alt_bier](https://twitter.com/alt_bier)  - [My Contact Info](https://gowen.net/about)

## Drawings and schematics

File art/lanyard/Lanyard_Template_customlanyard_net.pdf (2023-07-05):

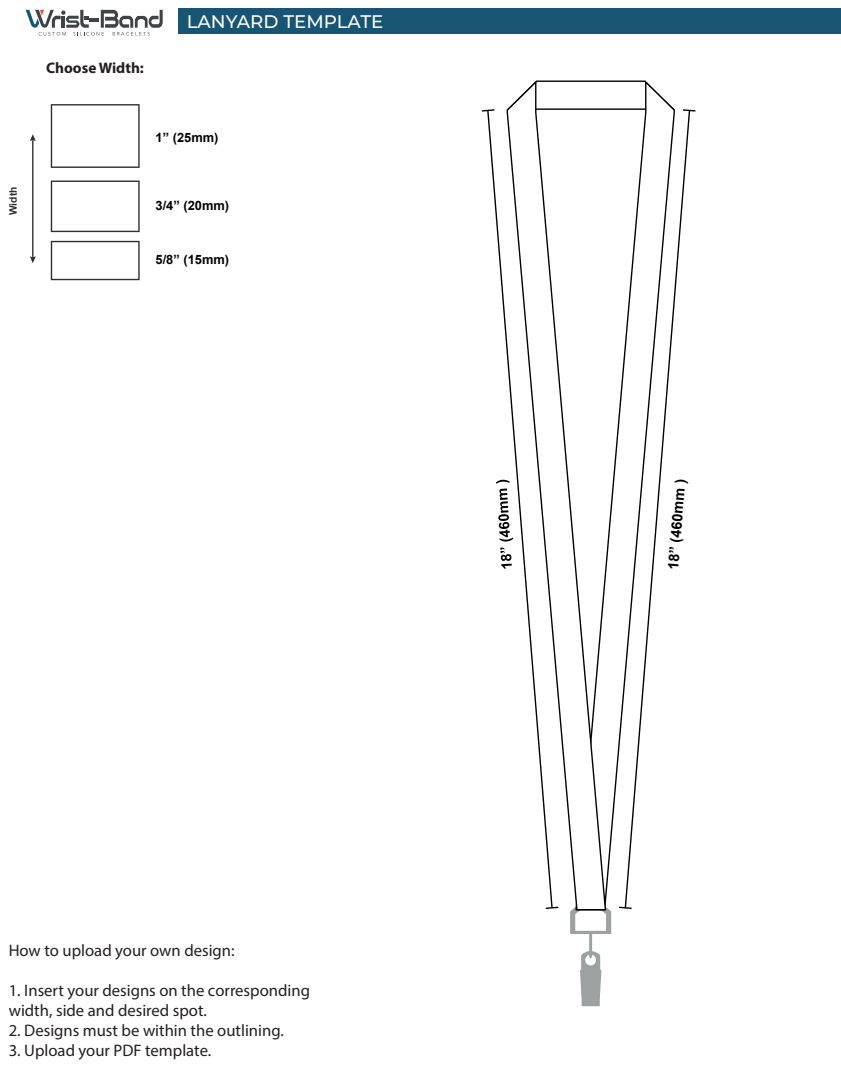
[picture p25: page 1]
Width; LANYARD TEMPLATE; Choose Width:

How to upload your own design:

1. Insert your designs on the corresponding
width, side and desired spot.
2. Designs must be within the outlining.
3. Upload your PDF template.

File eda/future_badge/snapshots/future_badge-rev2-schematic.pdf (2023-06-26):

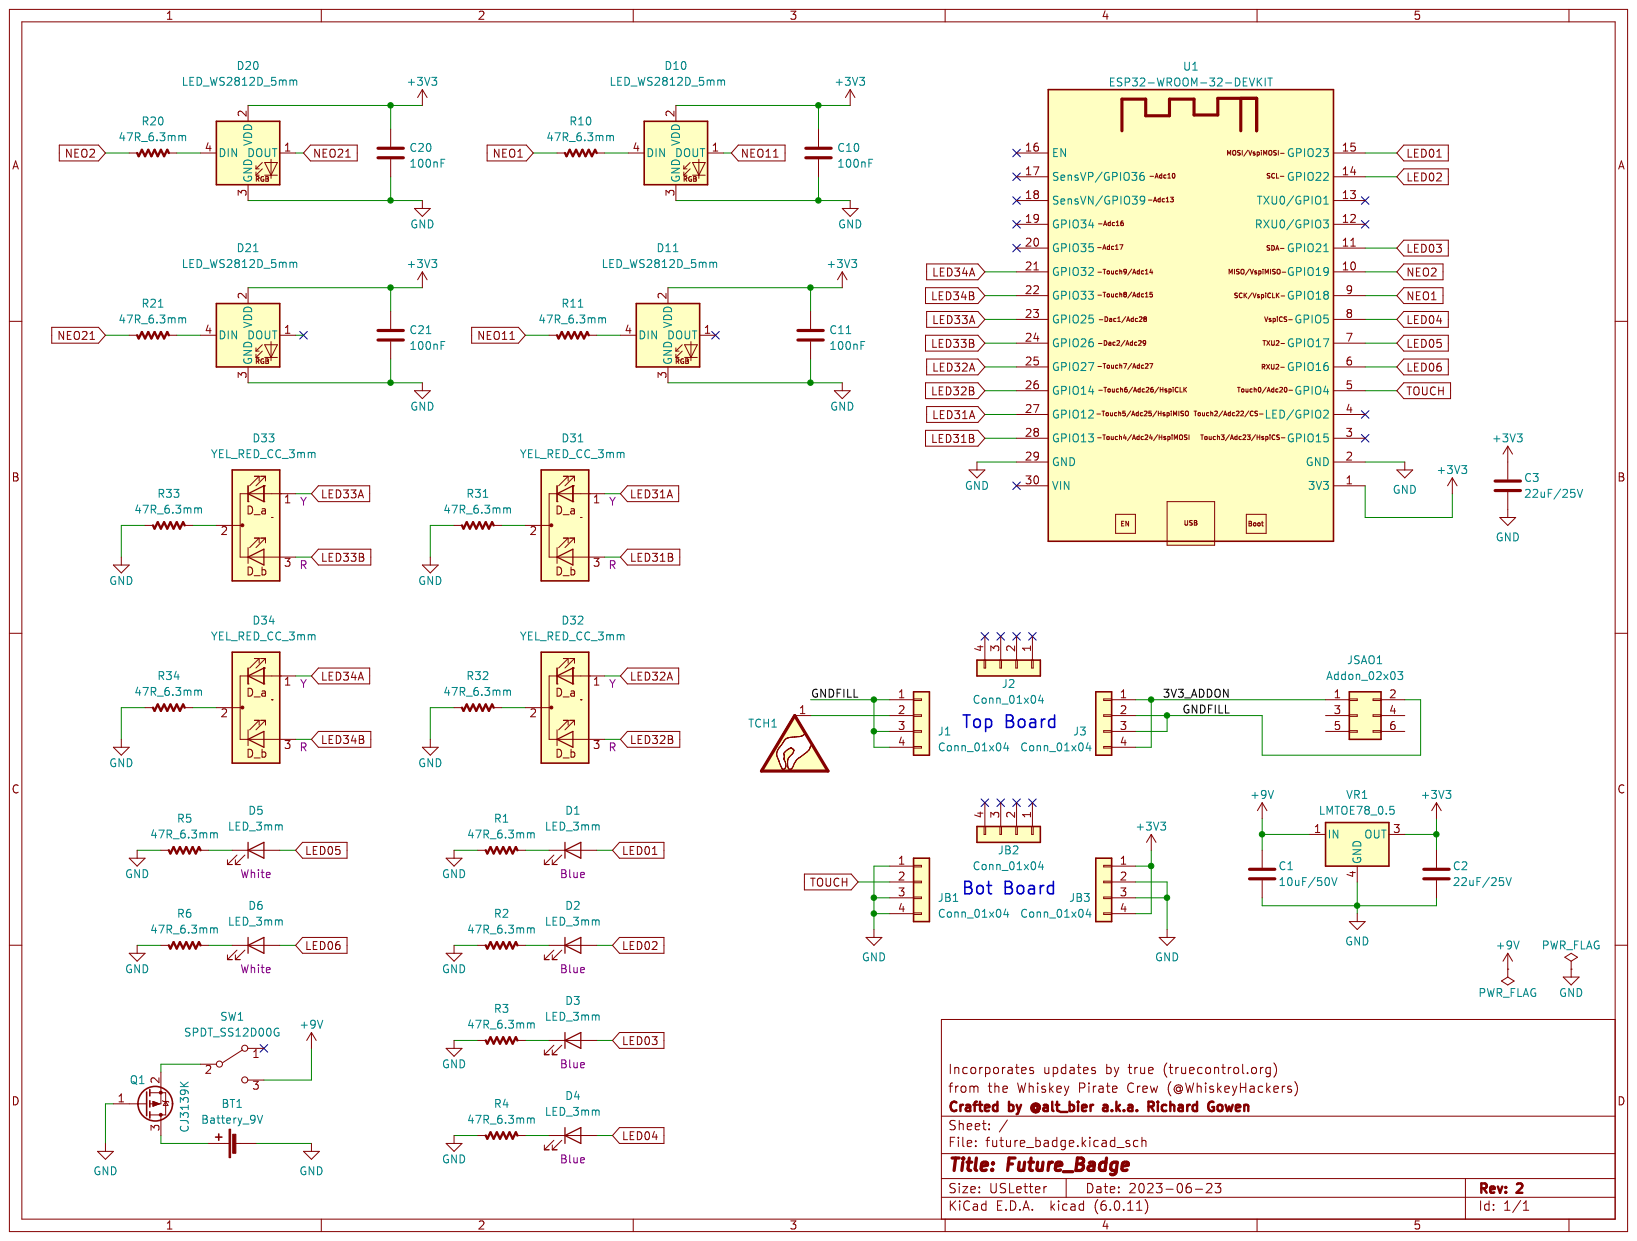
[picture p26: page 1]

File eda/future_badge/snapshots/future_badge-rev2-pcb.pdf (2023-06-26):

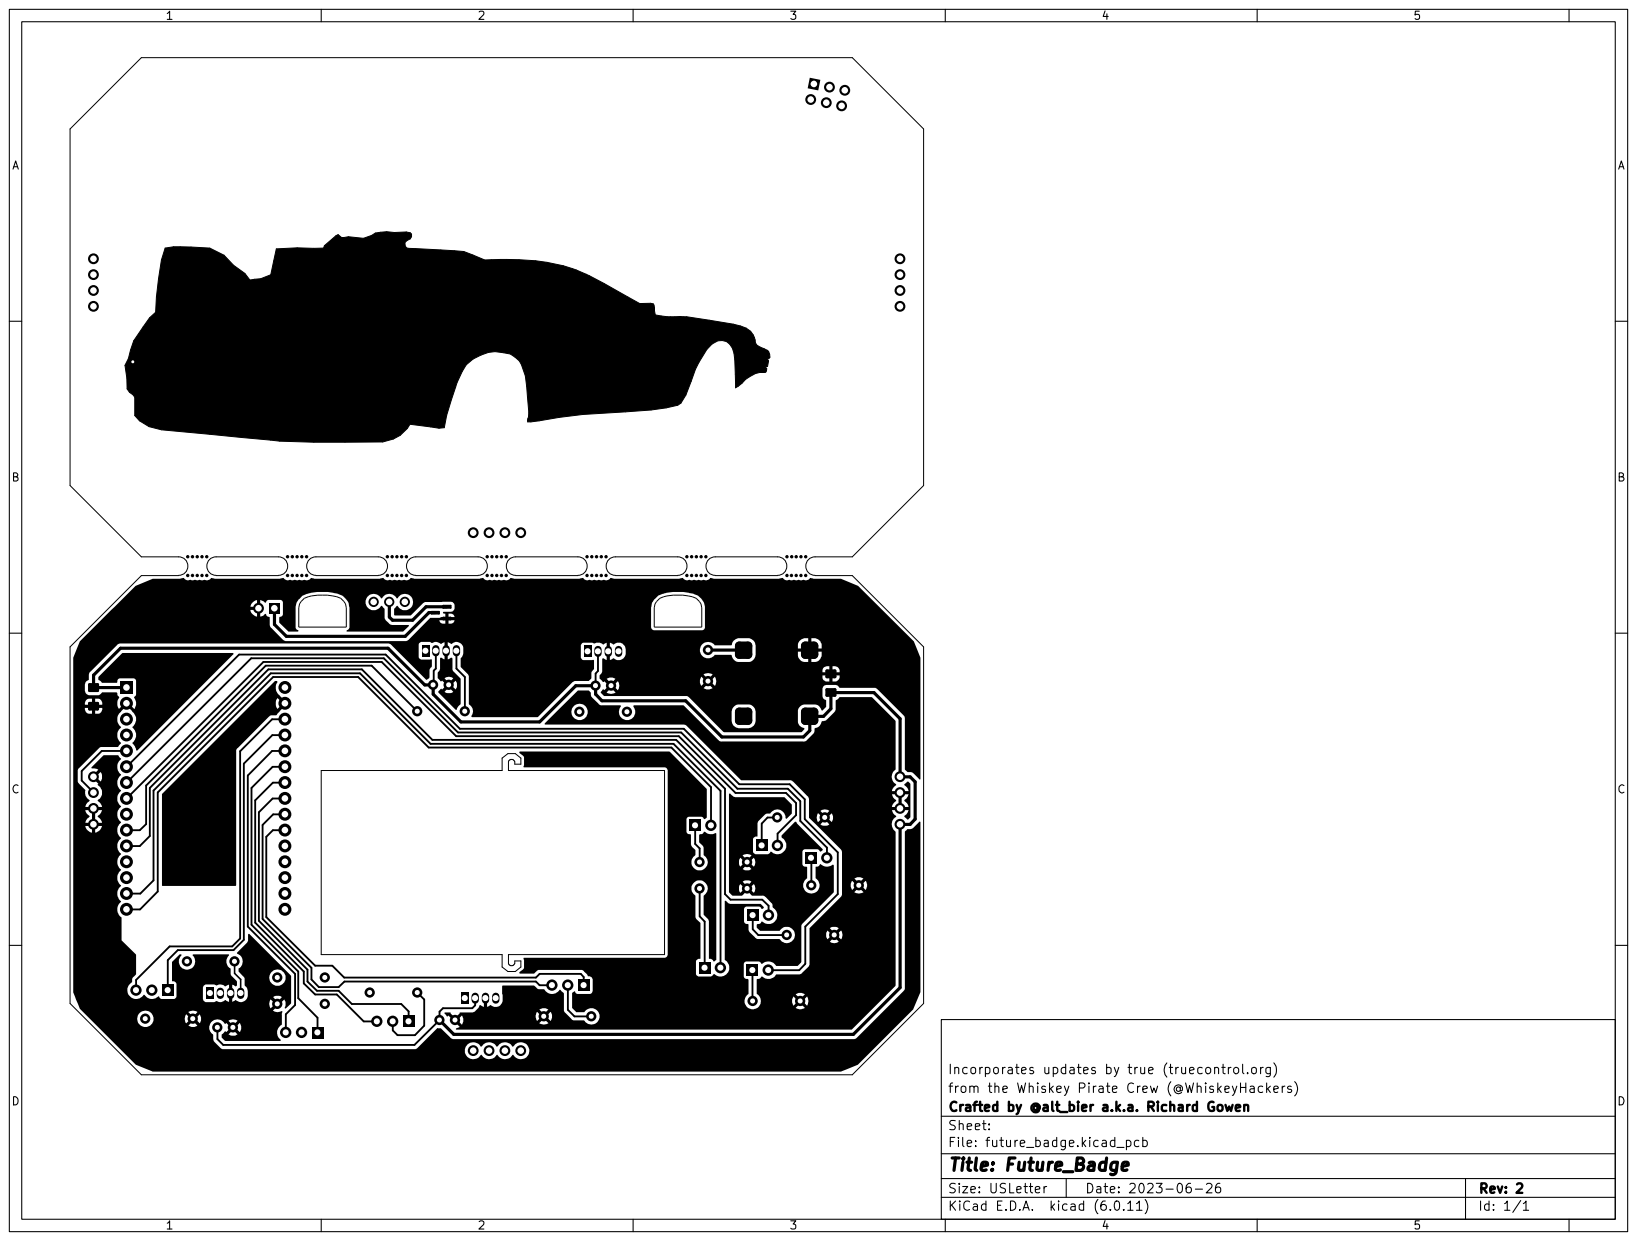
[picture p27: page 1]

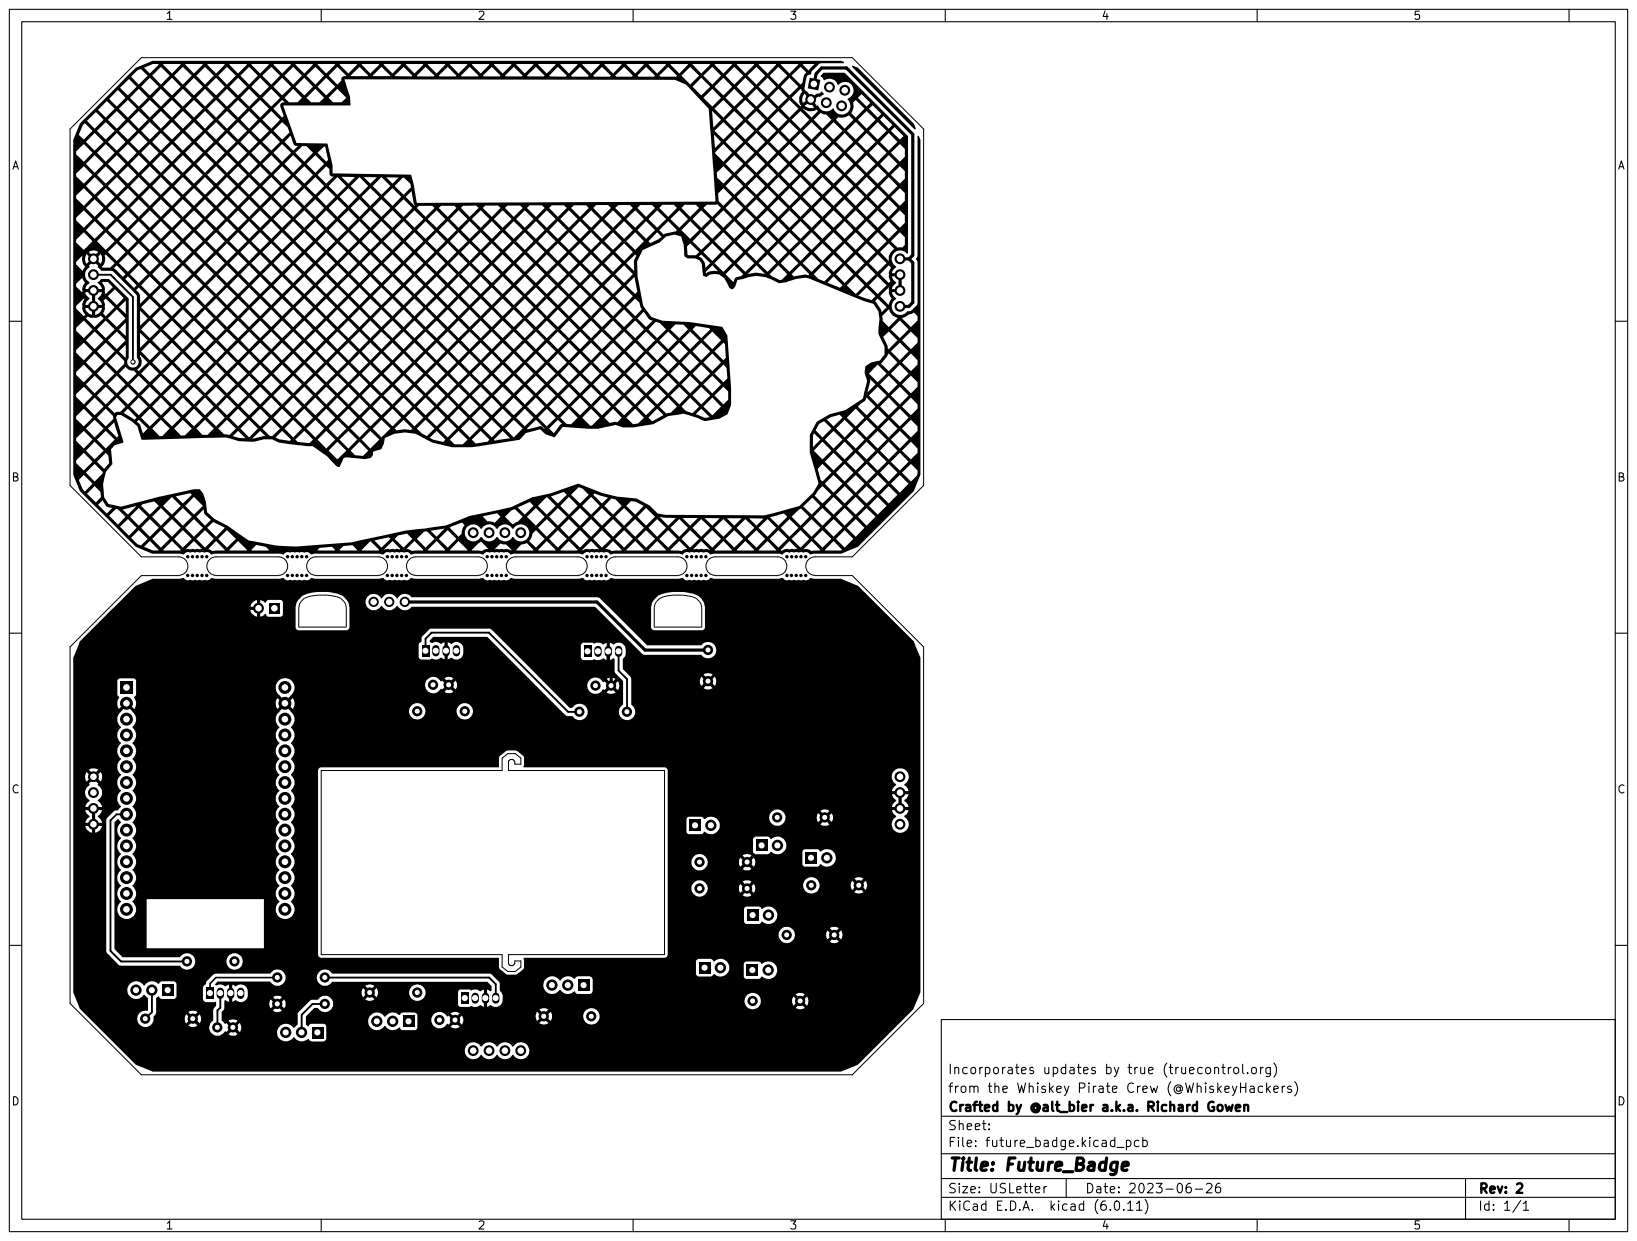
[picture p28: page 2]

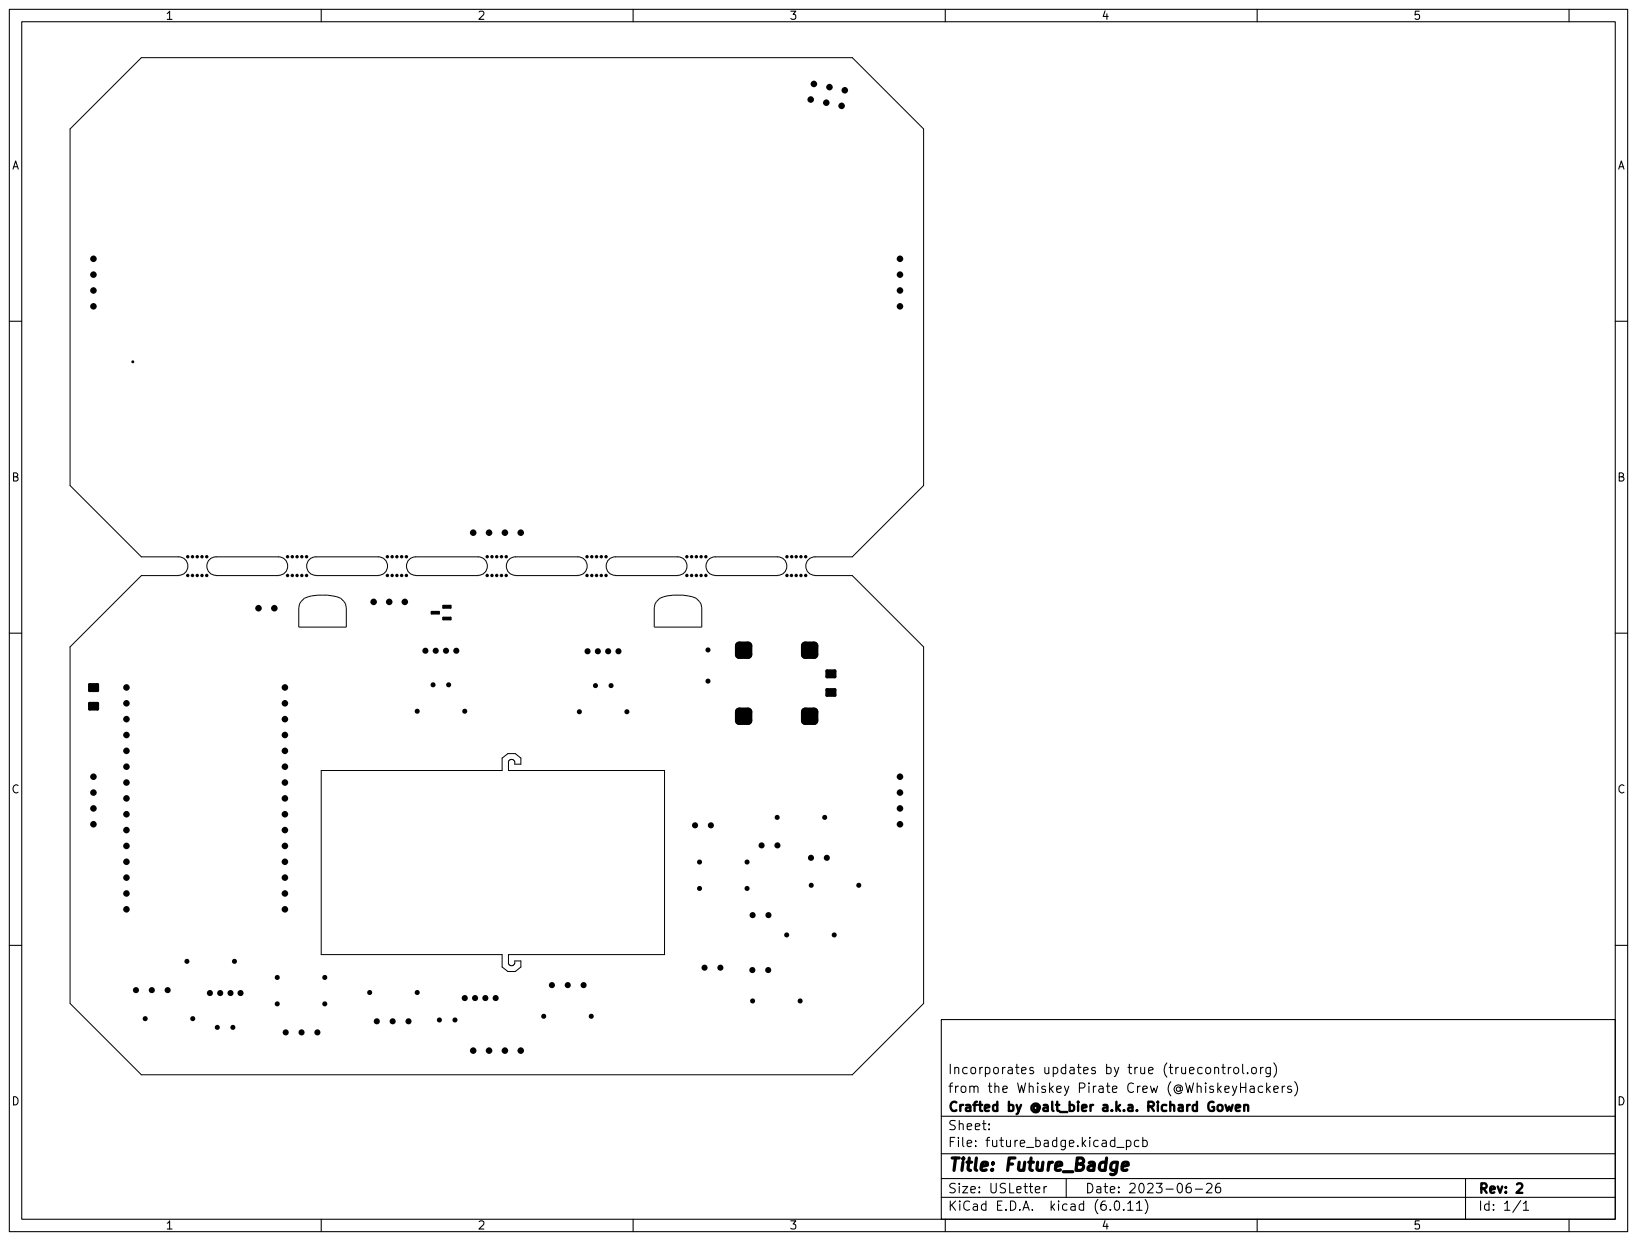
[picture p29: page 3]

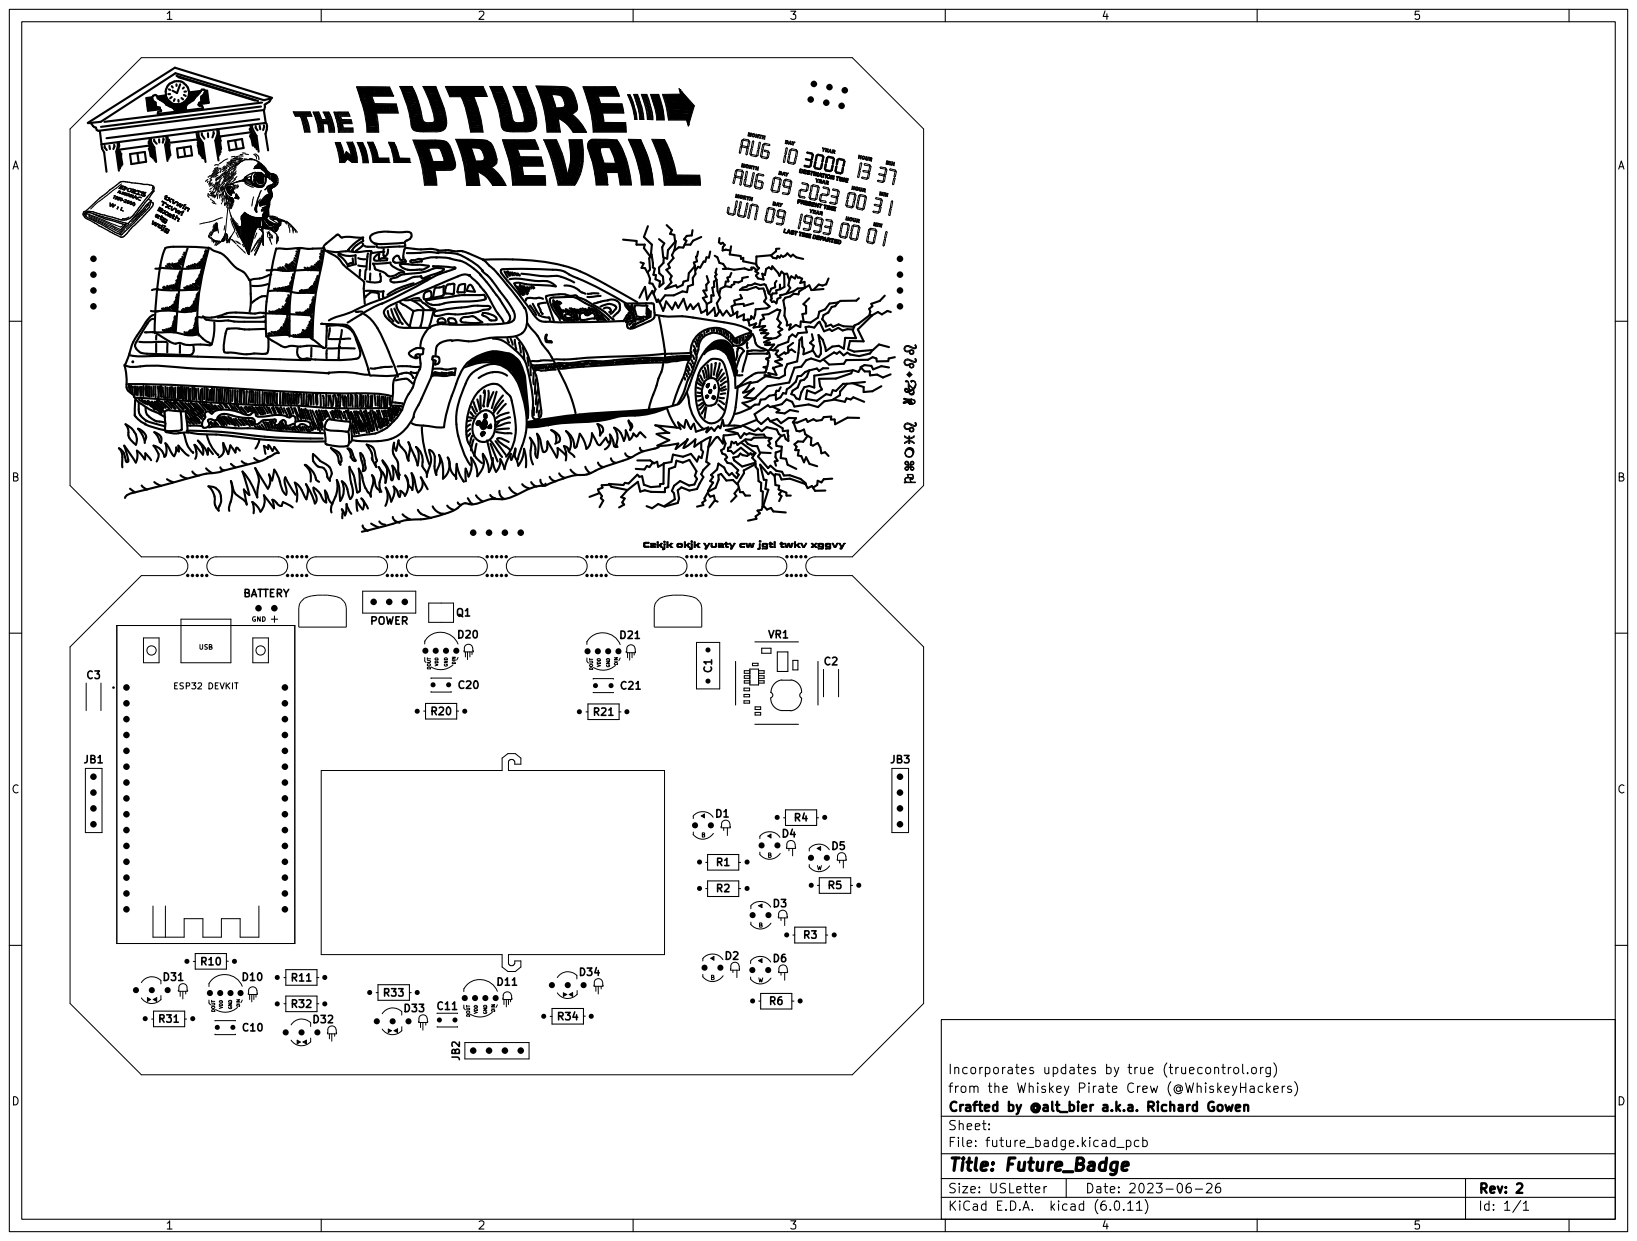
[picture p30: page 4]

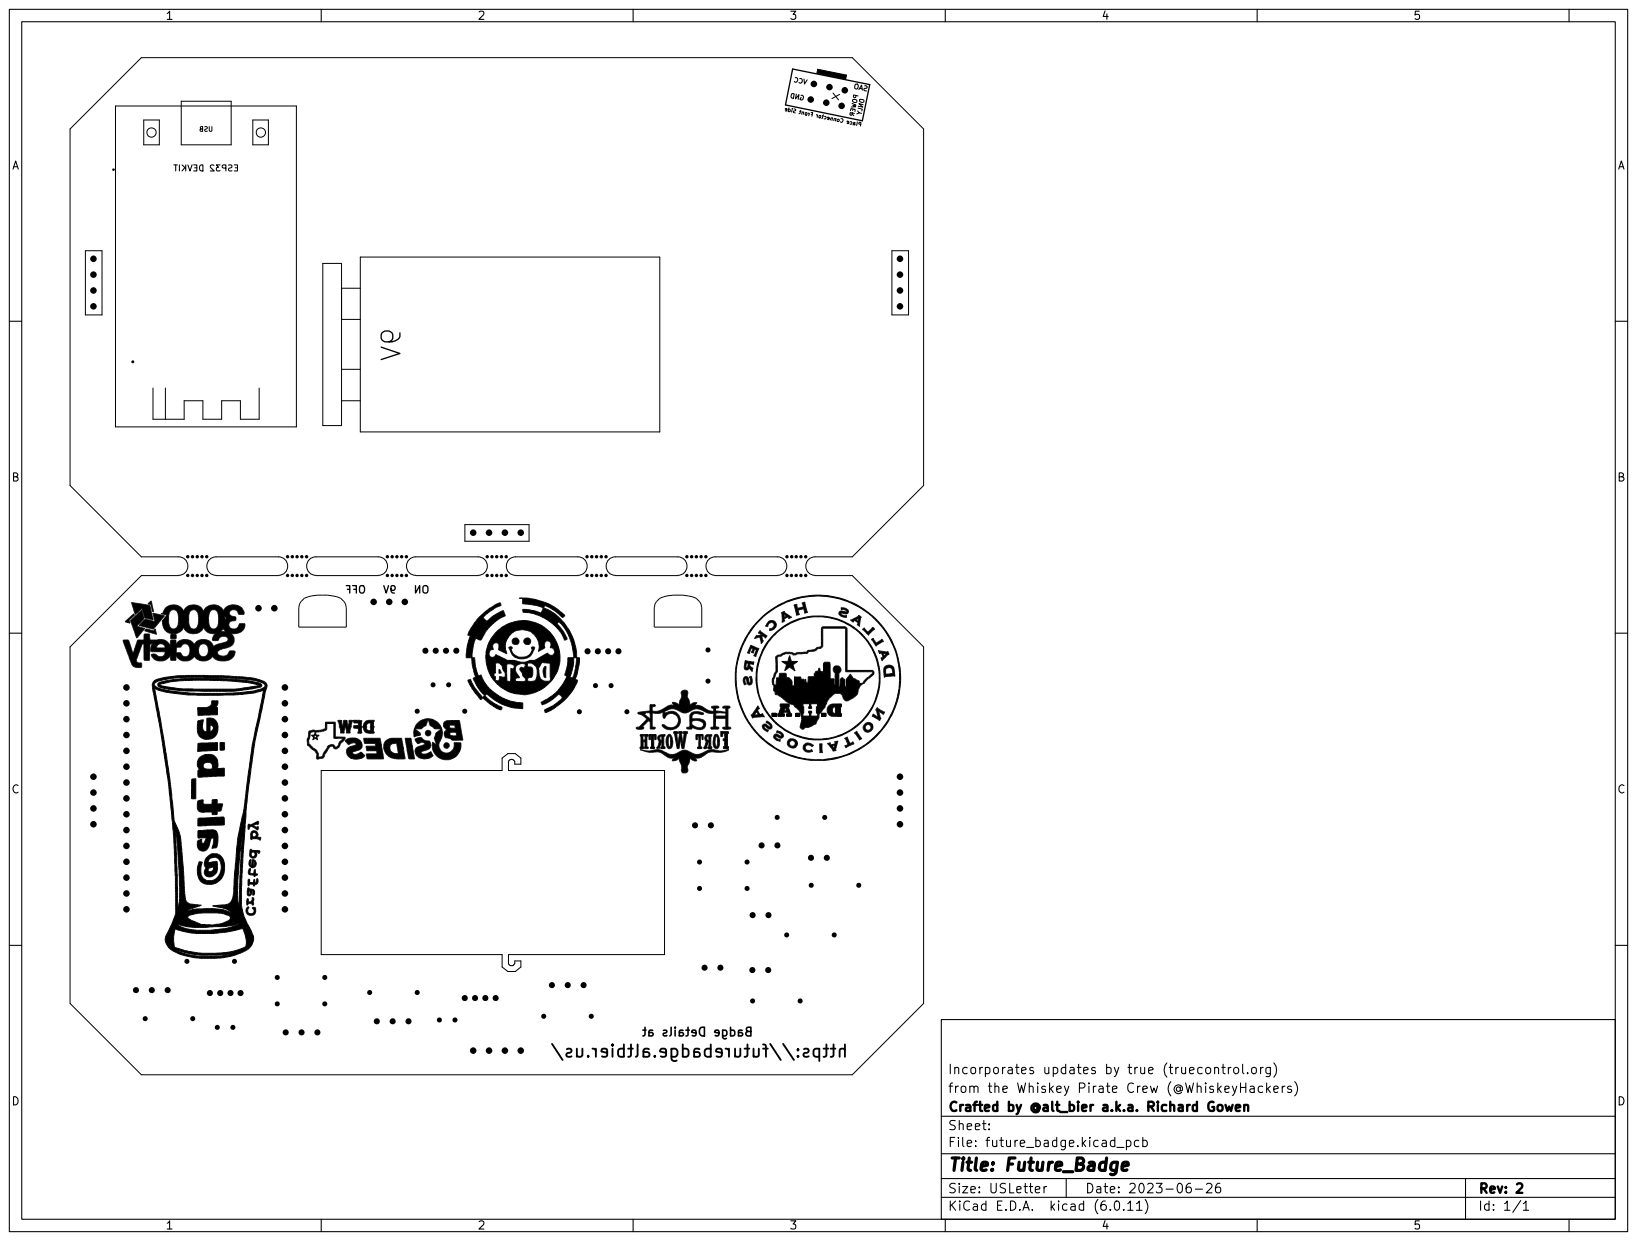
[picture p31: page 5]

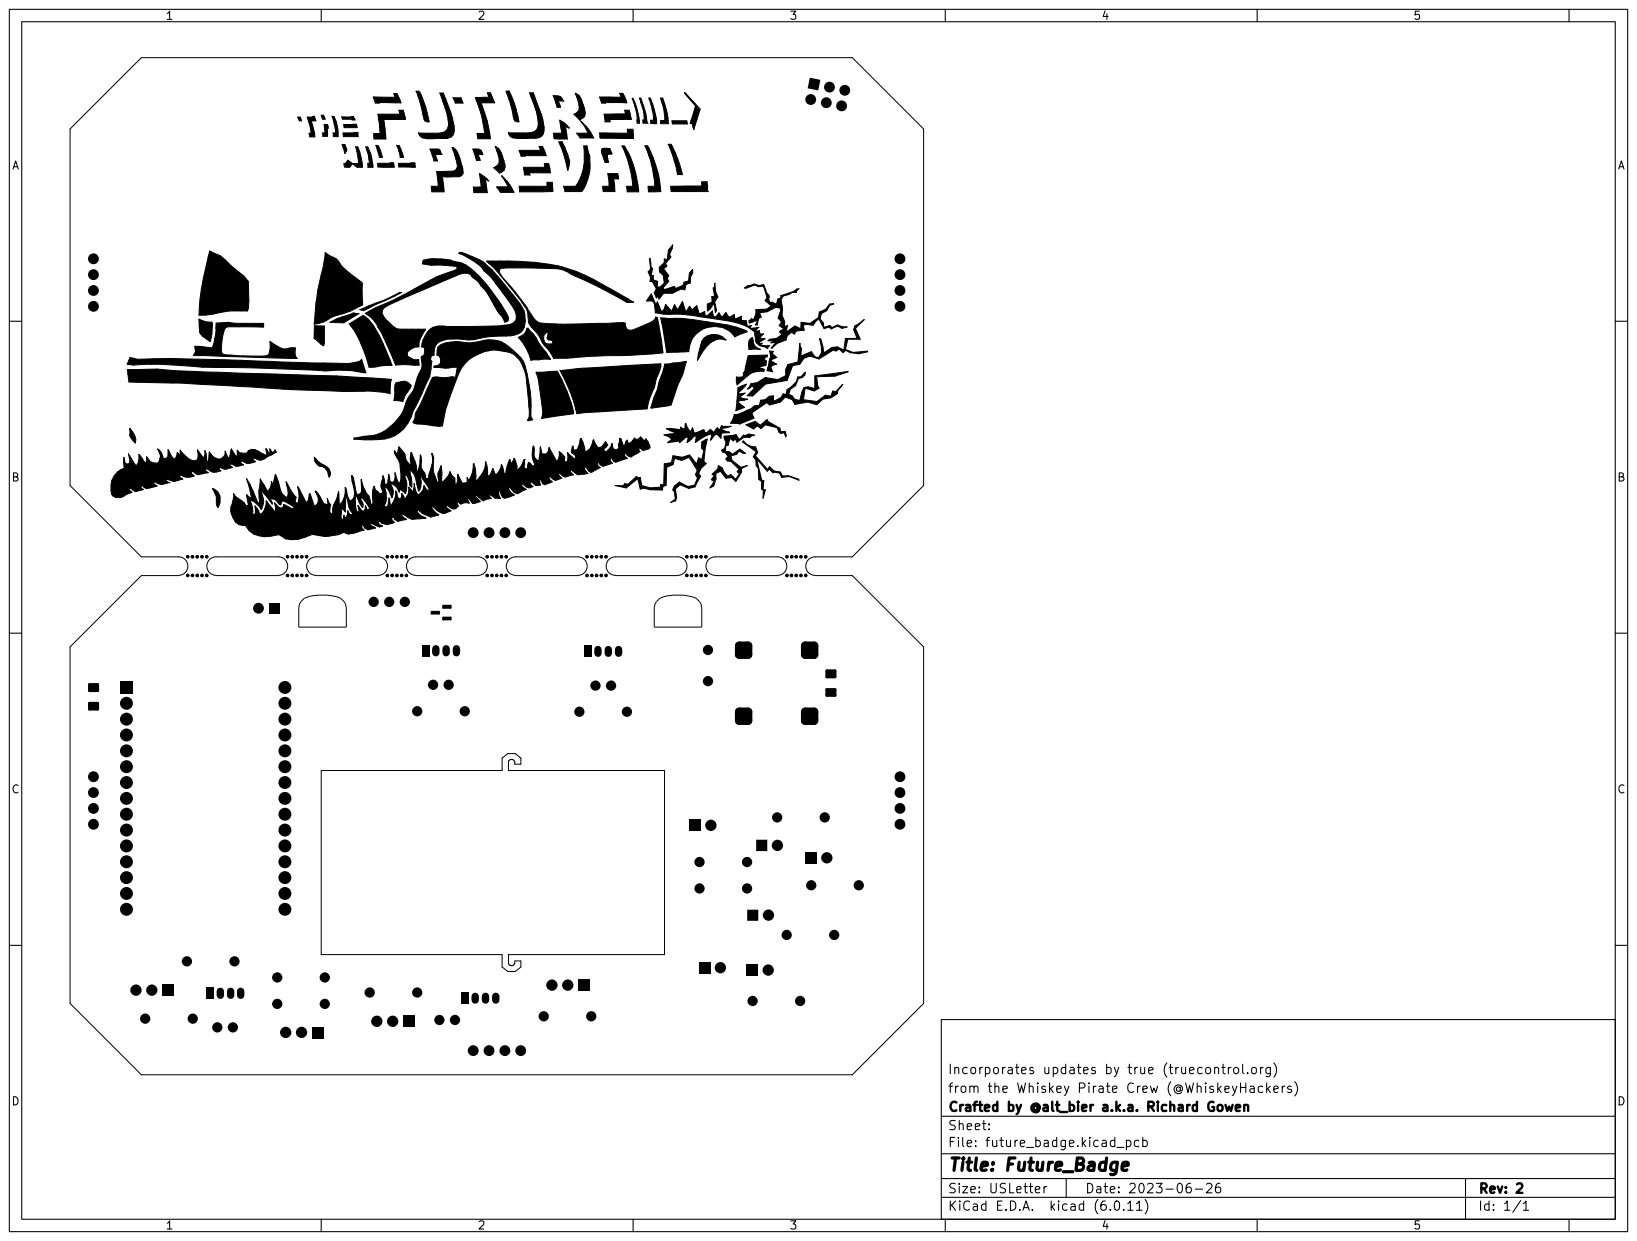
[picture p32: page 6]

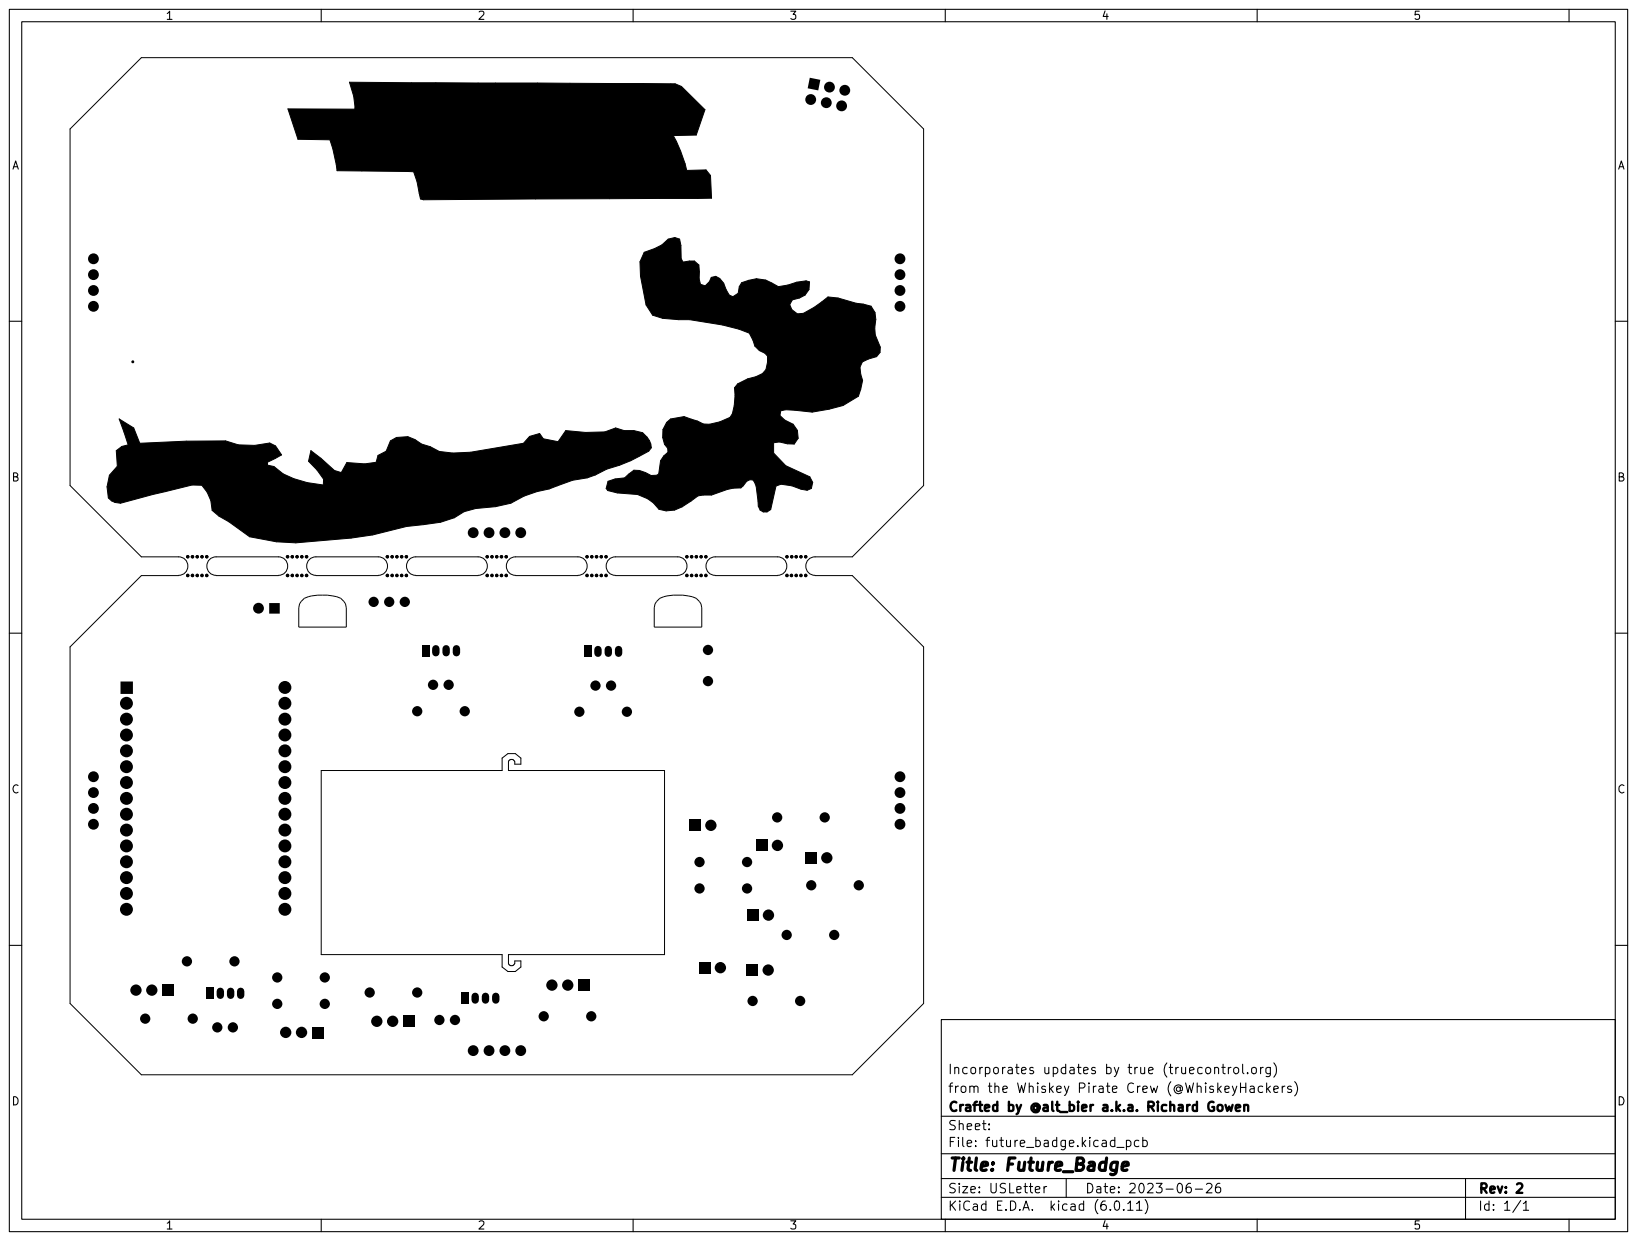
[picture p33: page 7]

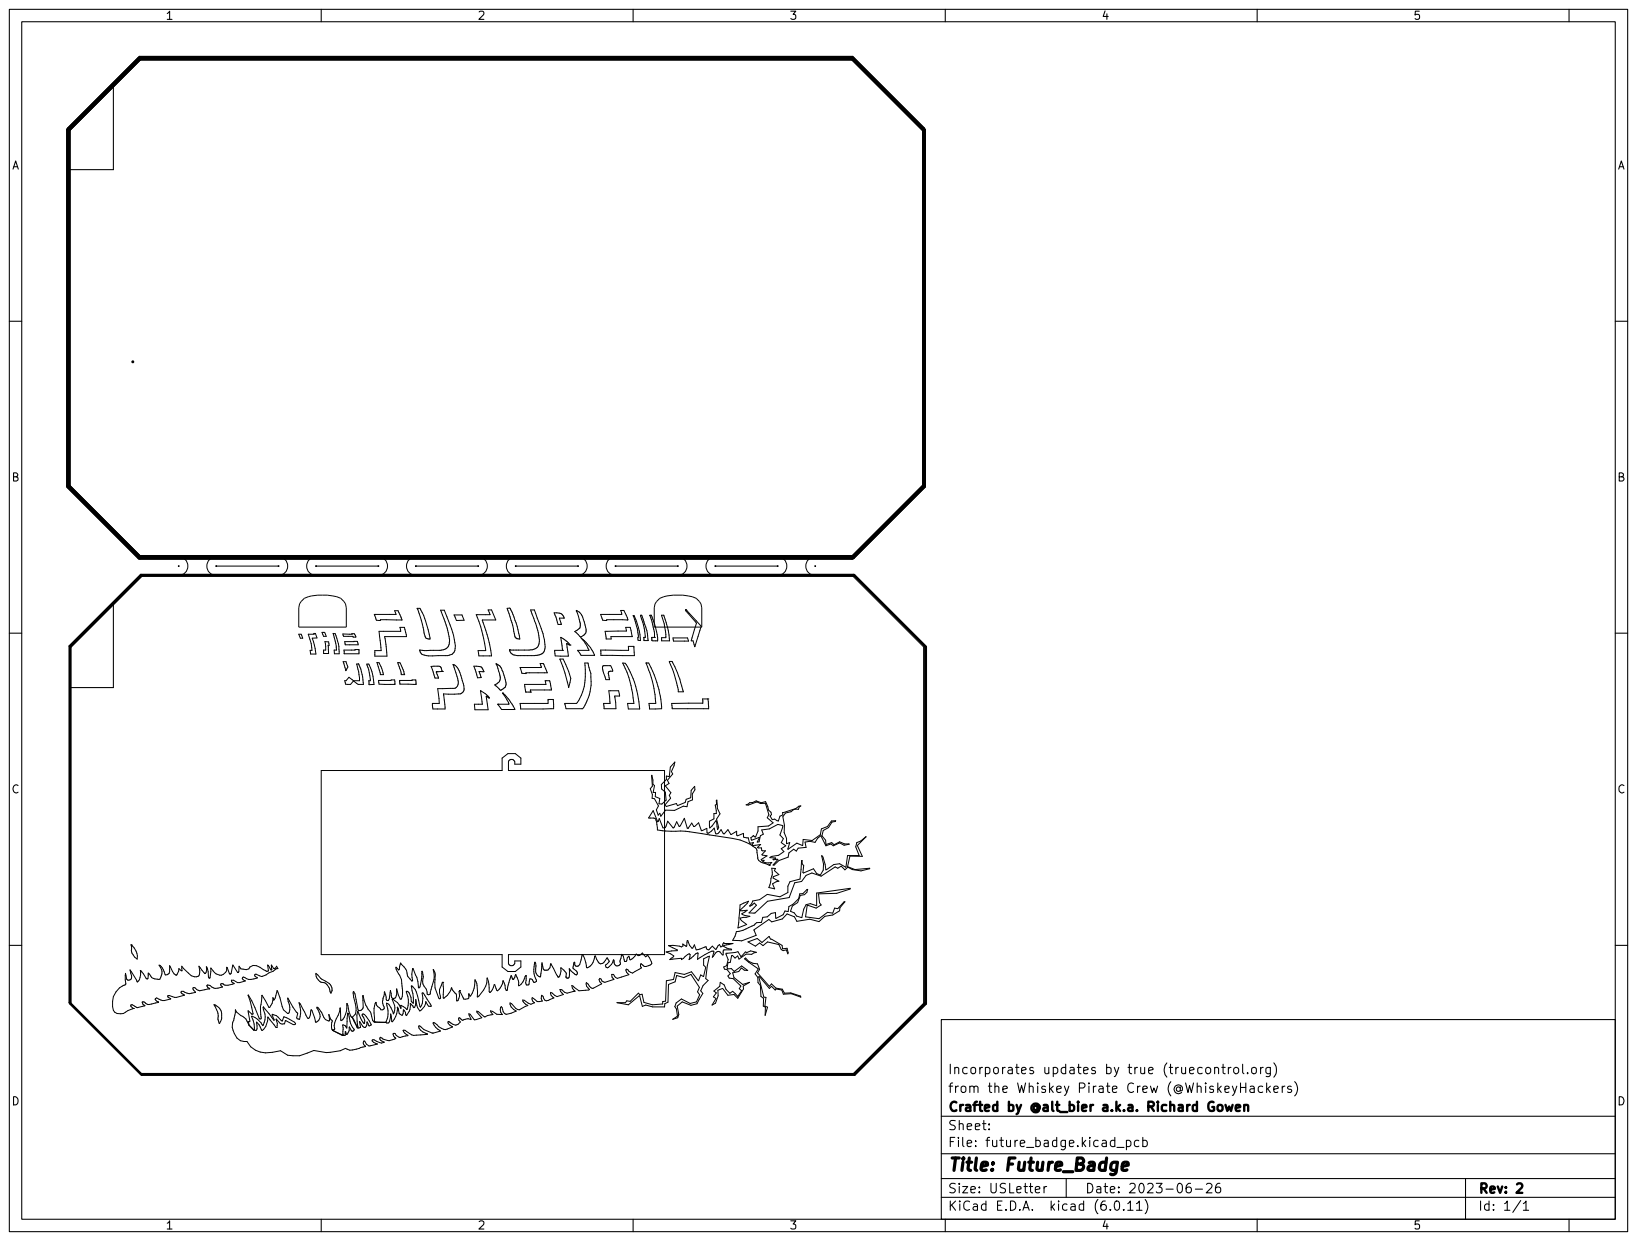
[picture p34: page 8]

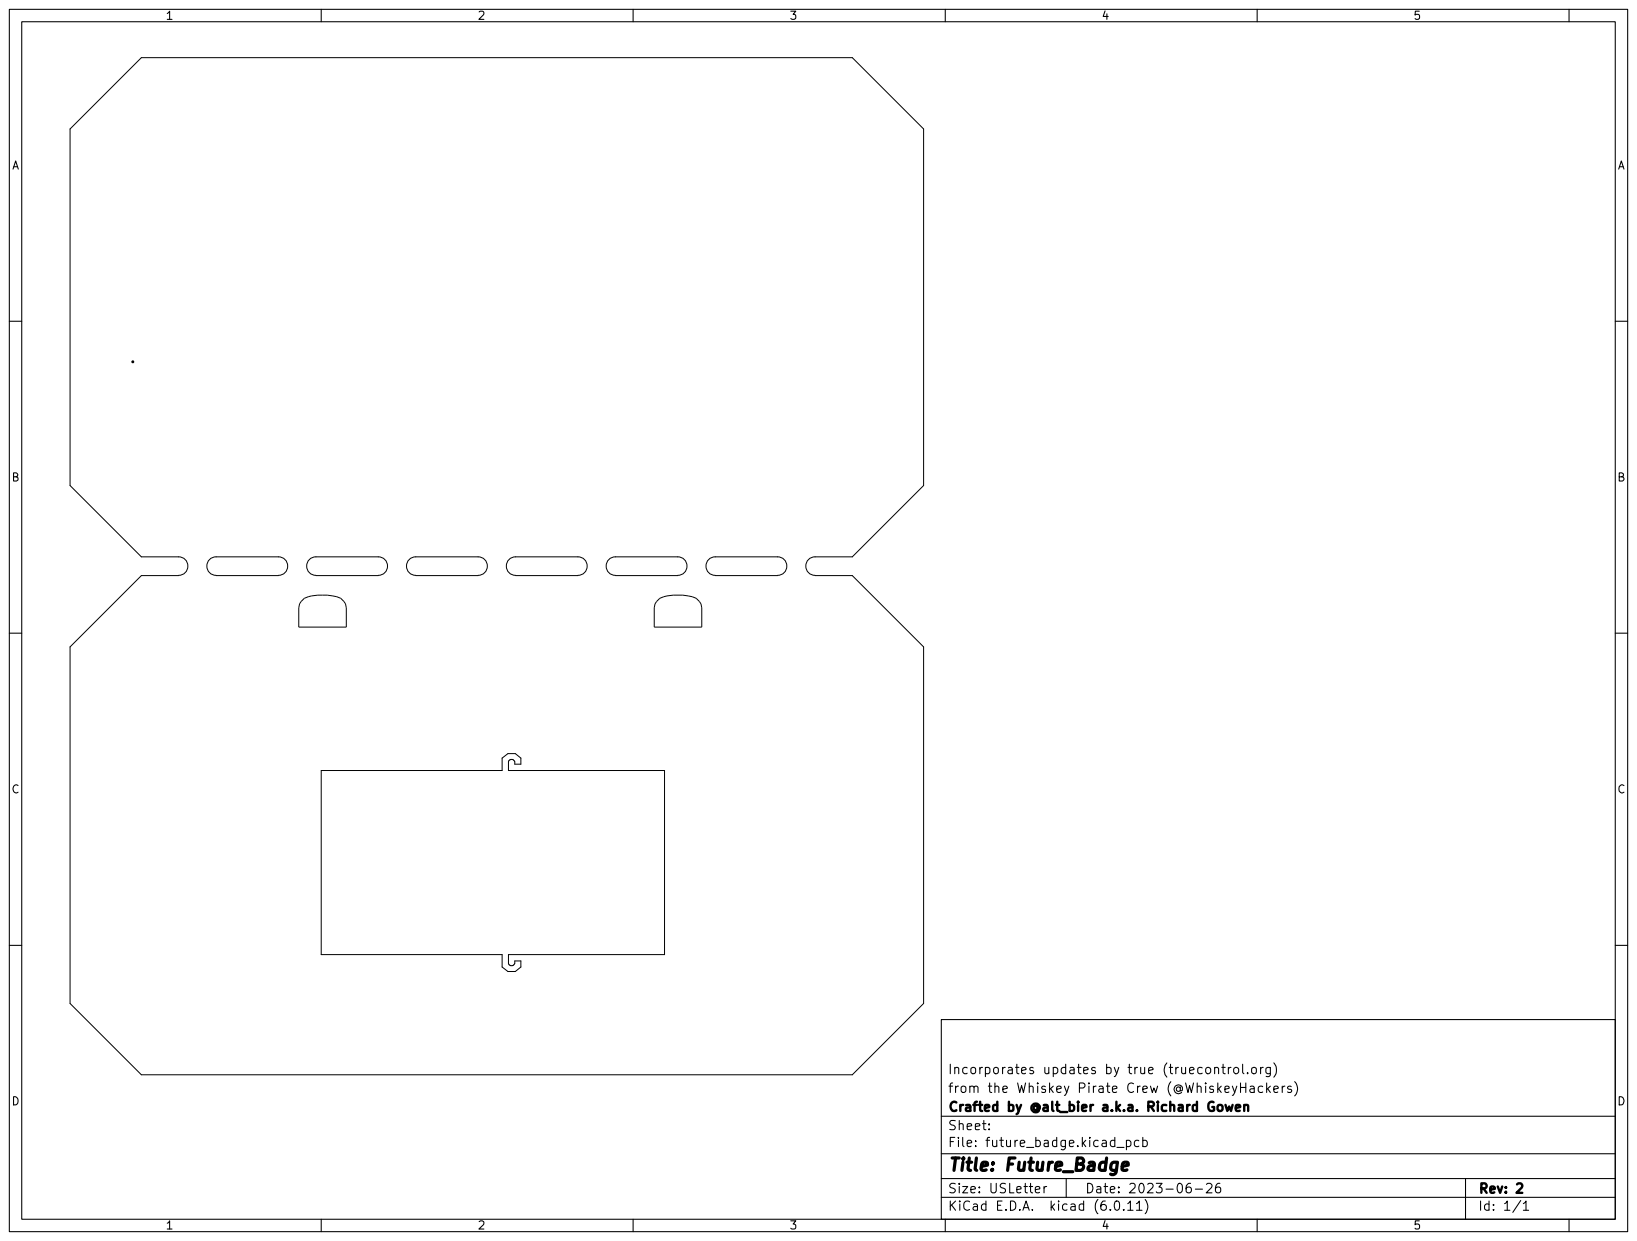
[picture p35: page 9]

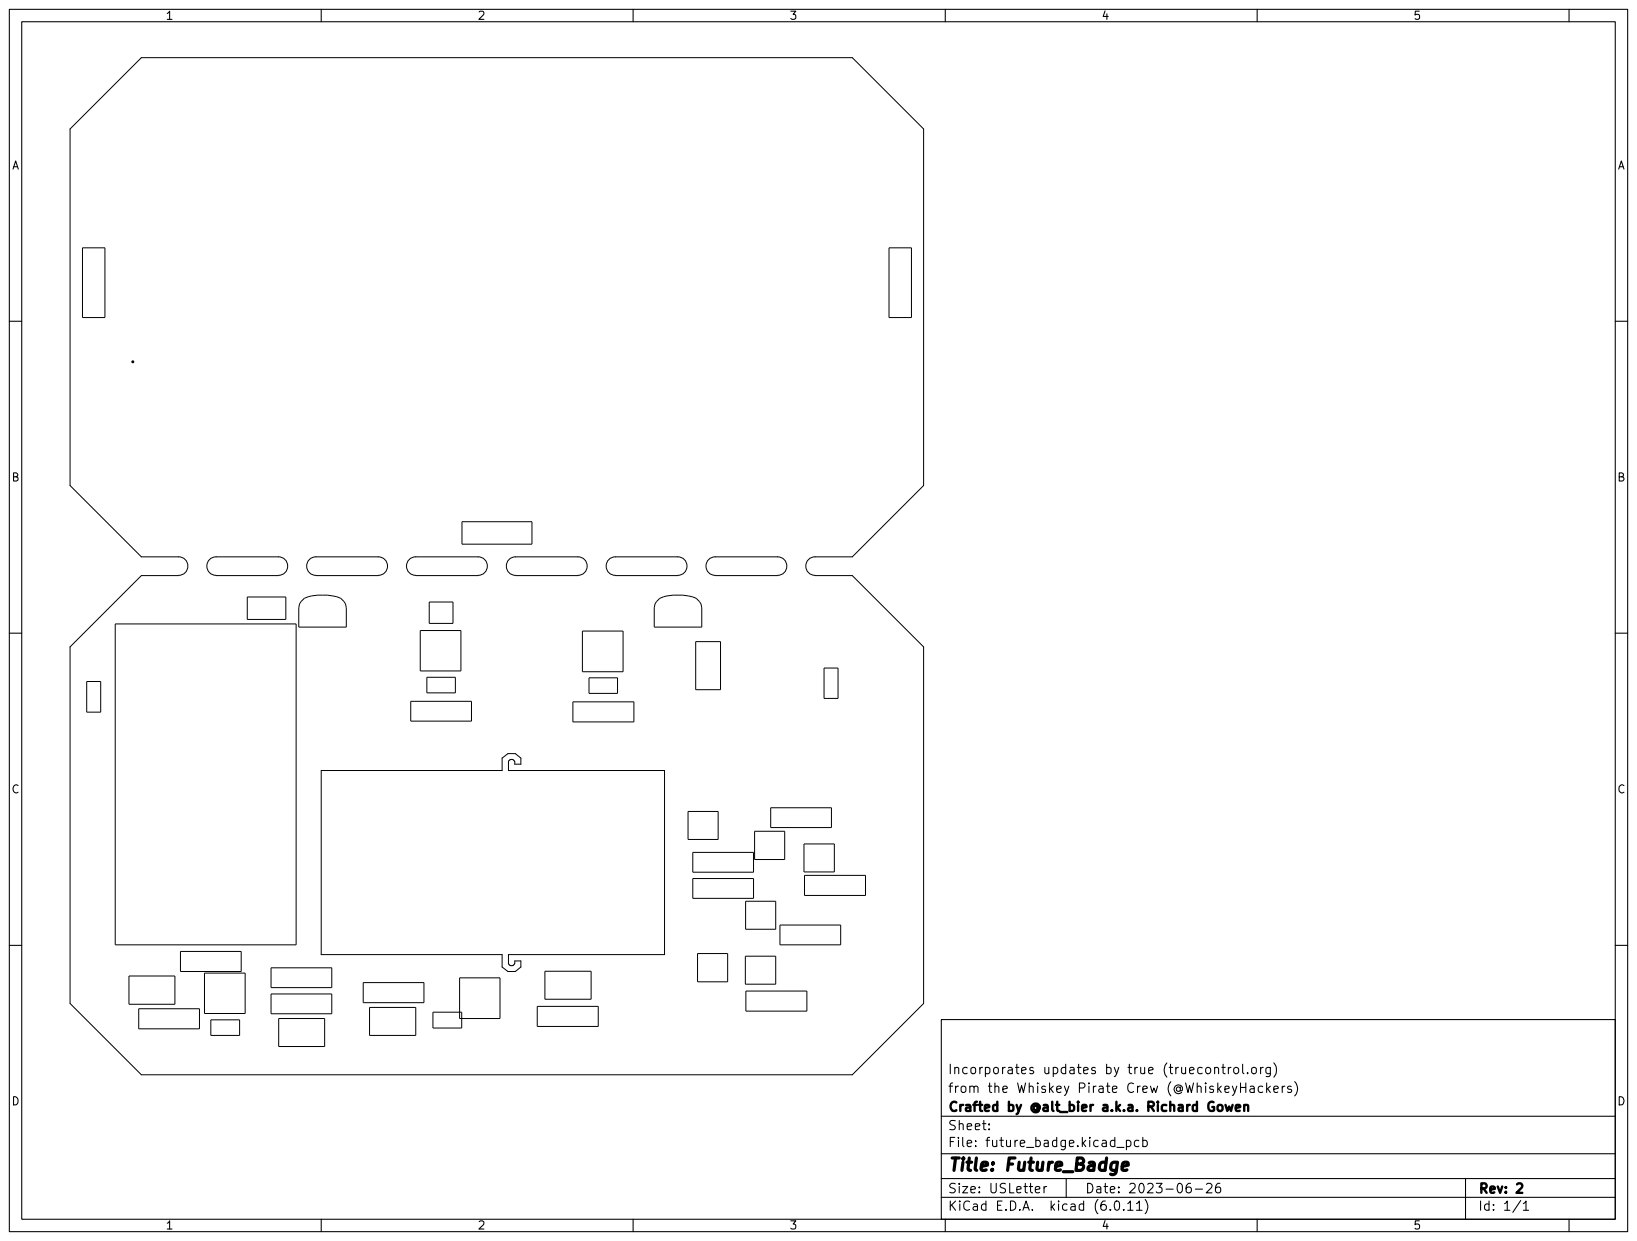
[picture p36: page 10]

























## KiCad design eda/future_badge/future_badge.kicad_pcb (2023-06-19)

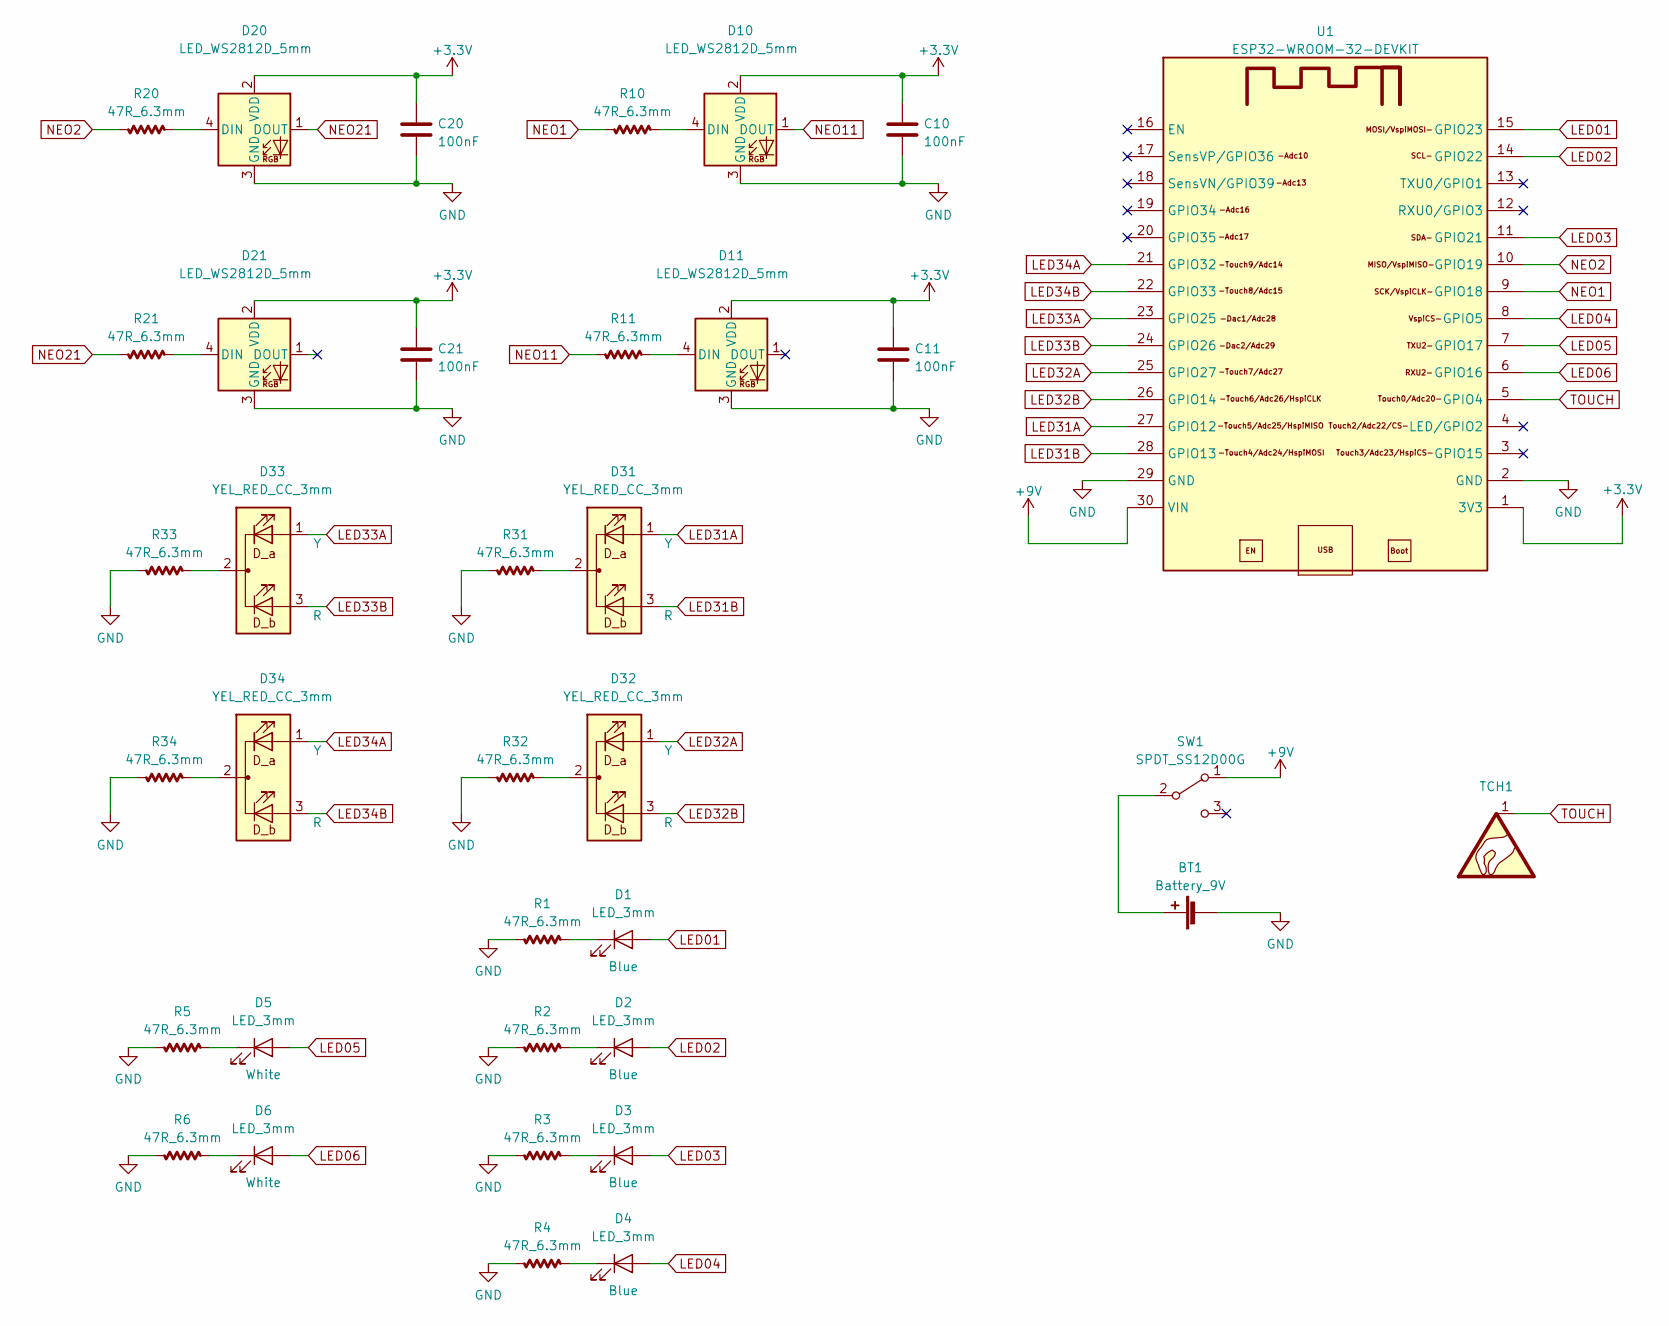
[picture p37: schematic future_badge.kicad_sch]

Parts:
BT1: Battery_9V; Battery_Lead_Wire_Connector
C10, C11, C20, C21: 100nF; C_Disc_D3.0mm_W2.0mm_P2.50mm
D1, D2, D3, D4, D5, D6: LED_3mm; LED_D3.0mm-2
D10, D11, D20, D21: LED_WS2812D_5mm; LED_D5.0mm-4_WS2812D_front_new
D31, D32, D33, D34: YEL_RED_CC_3mm; LED_D3.0mm-3-TwoColor
R1, R2, R3, R4, R5, R6, R10, R11, R20, R21, R31, R32, R33, R34: 47R_6.3mm; R_Axial_DIN0207_L6.3mm_D2.5mm_P7.62mm_Horizontal
SW1: SPDT_SS12D00G; SW_SPDT_Slide_SS12D00G-1P2T_3pin
TCH1: SYM_Touch_lg
U1: ESP32-WROOM-32-DEVKIT; ESP32_DEVKIT_V1

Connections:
+3.3V: C10.1, C11.1, C20.1, C21.1, D10.2 (VDD), D11.2 (VDD), D20.2 (VDD), D21.2 (VDD), U1.1 (3V3)
+9V: SW1.1 (A), U1.30 (VIN)
GND: BT1.2 (-), C10.2, C11.2, C20.2, C21.2, D10.3 (GND), D11.3 (GND), D20.3 (GND), D21.3 (GND), R1.1, R2.1, R3.1, R4.1, R5.1, R6.1, R31.1, R32.1, R33.1, R34.1, U1.2 (GND), U1.29 (GND)
LED01: D1.2 (A), U1.15 (GPIO23)
LED02: D2.2 (A), U1.14 (GPIO22)
LED03: D3.2 (A), U1.11 (GPIO21)
LED04: D4.2 (A), U1.8 (GPIO5)
LED05: D5.2 (A), U1.7 (GPIO17)
LED06: D6.2 (A), U1.6 (GPIO16)
LED31A: D31.1 (RA), U1.27 (GPIO12)
LED31B: D31.3 (BA), U1.28 (GPIO13)
LED32A: D32.1 (RA), U1.25 (GPIO27)
LED32B: D32.3 (BA), U1.26 (GPIO14)
LED33A: D33.1 (RA), U1.23 (GPIO25)
LED33B: D33.3 (BA), U1.24 (GPIO26)
LED34A: D34.1 (RA), U1.21 (GPIO32)
LED34B: D34.3 (BA), U1.22 (GPIO33)
NEO1: R10.1, U1.9 (GPIO18)
NEO2: R20.1, U1.10 (GPIO19)
NEO11: D10.1 (DOUT), R11.1
NEO21: D20.1 (DOUT), R21.1
unnamed: BT1.1 (+), SW1.2 (B)
unnamed: D1.1 (K), R1.2
unnamed: D2.1 (K), R2.2
unnamed: D3.1 (K), R3.2
unnamed: D4.1 (K), R4.2
unnamed: D5.1 (K), R5.2
unnamed: D6.1 (K), R6.2
unnamed: D10.4 (DIN), R10.2
unnamed: D11.4 (DIN), R11.2
unnamed: D20.4 (DIN), R20.2
unnamed: D21.4 (DIN), R21.2
unnamed: D31.2 (K), R31.2
unnamed: D32.2 (K), R32.2
unnamed: D33.2 (K), R33.2
unnamed: D34.2 (K), R34.2
TOUCH: TCH1.1, U1.5 (GPIO4)

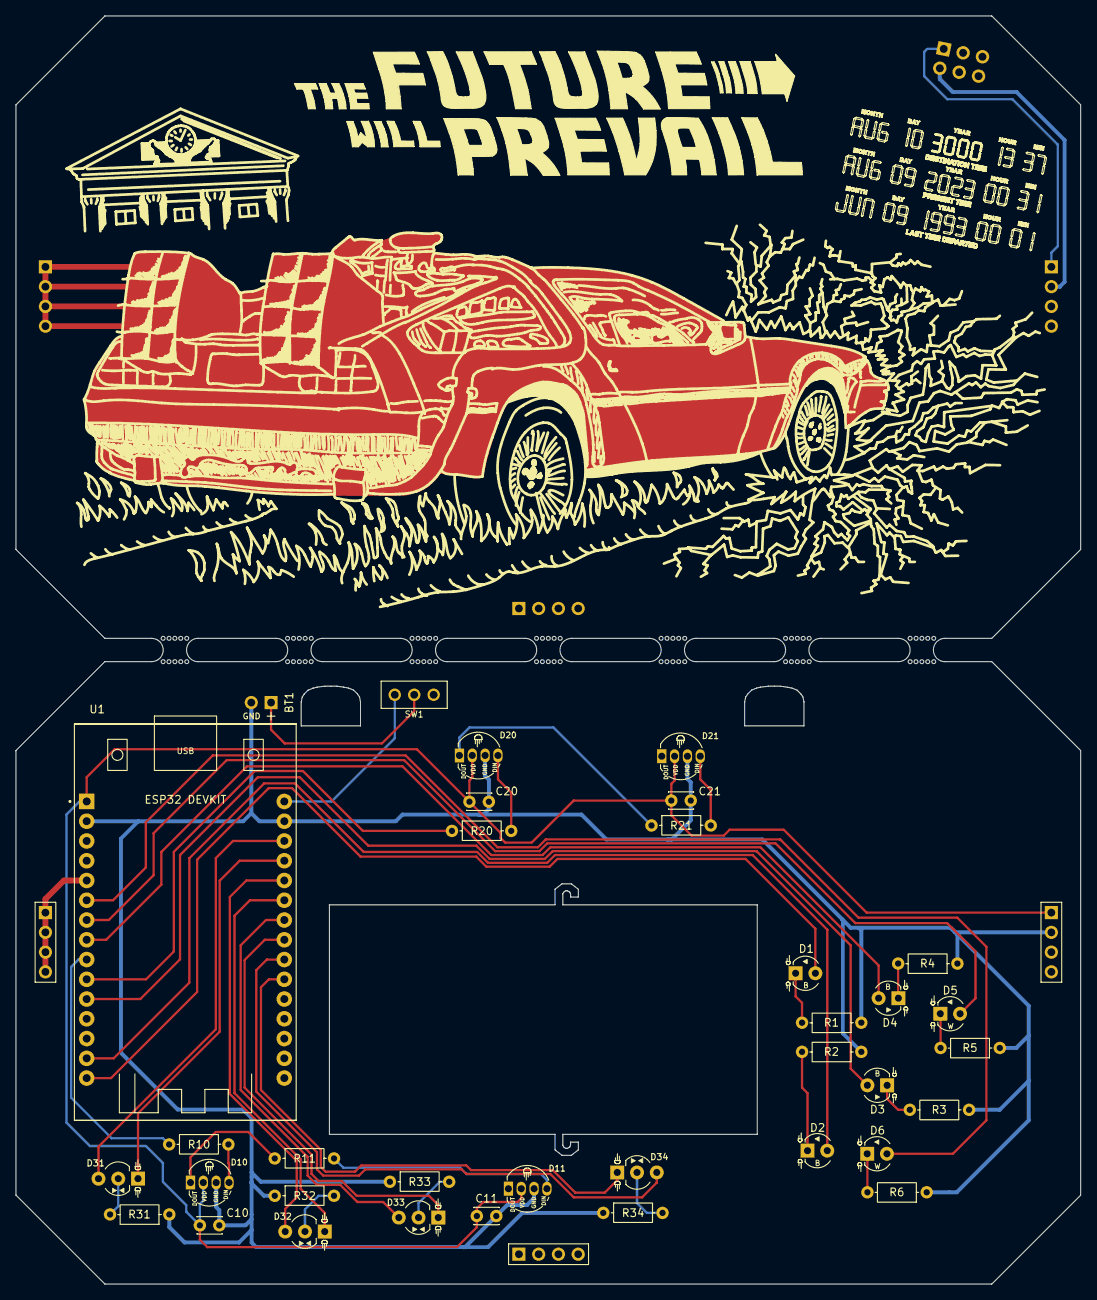
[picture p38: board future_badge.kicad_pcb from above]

Board: 2 copper layers, 136.9 x 163.0 mm, 35 parts (0 on the bottom side), 36 nets.

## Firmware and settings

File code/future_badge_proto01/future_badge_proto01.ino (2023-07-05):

#include <Adafruit_NeoPixel.h>
#include <WiFi.h>

// NeoPixel PIN VALUES
#define NEO01Pin 18   // 18 corresponds to GPIO18
#define NEO02Pin 19   // 18 corresponds to GPIO19

// Two color RY LED PIN VALUES
// The A pin is Yellow and the B pin is Red
#define LED31A 12  // 12 corresponds to GPIO12
#define LED31B 13  // 13 corresponds to GPIO13
#define LED32A 27
#define LED32B 14
#define LED33A 25
#define LED33B 26
#define LED34A 32
#define LED34B 33

// One color B/W LED PIN VALUES
#define LEDB01 23
#define LEDB02 22
#define LEDB03 21
#define LEDB04 5
#define LEDW05 17
#define LEDW06 16

// Touch PIN VALUE
#define TouchPin 4  // 4 corresponds to GPIO4 - Touch0

// PWM Properties
const int freq = 1000;
const int resolution = 8;
const int LED31Apwm = 0;
const int LED31Bpwm = 1;
const int LED32Apwm = 2;
const int LED32Bpwm = 3;
const int LED33Apwm = 4;
const int LED33Bpwm = 5;
const int LED34Apwm = 6;
const int LED34Bpwm = 7;

// Define NeoPixel Strips - (Num pixels, pin to send signals, pixel type, signal rate)
Adafruit_NeoPixel NEO01 = Adafruit_NeoPixel(2, NEO01Pin, NEO_RGB + NEO_KHZ800);
Adafruit_NeoPixel NEO02 = Adafruit_NeoPixel(2, NEO02Pin, NEO_RGB + NEO_KHZ800);

// Touch Properties
int TouchThreshold = 12;
int TouchValue = 13;

// SETUP - RUN ONCE
void setup(){
  // Turn Off WiFi
  WiFi.mode(WIFI_OFF);

  // configure LED PWM functionalitites per channel
  ledcSetup(LED31Apwm, freq, resolution);
  ledcSetup(LED31Bpwm, freq, resolution);
  ledcSetup(LED32Apwm, freq, resolution);
  ledcSetup(LED32Bpwm, freq, resolution);
  ledcSetup(LED33Apwm, freq, resolution);
  ledcSetup(LED33Bpwm, freq, resolution);
  ledcSetup(LED34Apwm, freq, resolution);
  ledcSetup(LED34Bpwm, freq, resolution);

  // attach the channel to the GPIO to be controlled
  ledcAttachPin(LED31A, LED31Apwm);
  ledcAttachPin(LED31B, LED31Bpwm);
  ledcAttachPin(LED32A, LED32Apwm);
  ledcAttachPin(LED32B, LED32Bpwm);
  ledcAttachPin(LED33A, LED33Apwm);
  ledcAttachPin(LED33B, LED33Bpwm);
  ledcAttachPin(LED34A, LED34Apwm);
  ledcAttachPin(LED34B, LED34Bpwm);

  //Normal LED output
  pinMode(LEDB01, OUTPUT);
  pinMode(LEDB02, OUTPUT);
  pinMode(LEDB03, OUTPUT);
  pinMode(LEDB04, OUTPUT);
  pinMode(LEDW05, OUTPUT);
  pinMode(LEDW06, OUTPUT);

  // Initializes the NeoPixels
  NEO01.begin();
  NEO02.begin(); 

  // Set Neopixel Brightness (0-255 scale)
  NEO01.setBrightness(200);
  NEO02.setBrightness(200);
  
  // setup the serial output baud rate
  Serial.begin(115200);
}

// LOOP - MAIN 
void loop(){
  // Set Delay Time [in ms]
  int DelayTime = 20;

  // Dynamically adjust touch threshold UP to account for
  // Assembly conditions and battery vs usb
  TouchValue = touchRead(TouchPin);
  if ( (TouchValue / TouchThreshold) > 2 ) { TouchThreshold = int(TouchThreshold * 1.8); }

  // Iterate 0 to 255
  for(int i=0; i<256; i++){

    // Set position value to iteration
    int pos = i;
    //
    // First of three position groups 0-84
    if (pos < 85) {
      //
      // BLUE LEDS
      if (pos % 2) {
        digitalWrite(LEDB01, HIGH);
        digitalWrite(LEDB03, LOW);
      } else {
        digitalWrite(LEDB01, LOW);
        digitalWrite(LEDB03, HIGH);
      }
      digitalWrite(LEDB02, HIGH);
      digitalWrite(LEDB04, HIGH);
      // WHITE LEDS
      digitalWrite(LEDW05, LOW);
      digitalWrite(LEDW06, LOW);
      //
      // RY PWM LEDS
      //
      // Start off and slowly get brighter to full on
      ledcWrite(LED31Apwm, int(pos*3));
      ledcWrite(LED32Bpwm, int(pos*3));
      ledcWrite(LED33Apwm, int(pos*3));
      ledcWrite(LED34Bpwm, int(pos*3));
      // Start on and slowly get dimmer to full off
      ledcWrite(LED31Bpwm, int(255 - (pos*3)));
      ledcWrite(LED32Apwm, int(255 - (pos*3)));
      ledcWrite(LED33Bpwm, int(255 - (pos*3)));
      ledcWrite(LED34Apwm, int(255 - (pos*3)));
      //
      // Flame NeoPixel Red=ON Green=Cycle Blue=OFF (R+G=Y)
      //
      // Red 255 Green ++ Blue 0
      NEO01.setPixelColor(0, 255, int(pos), 0);
      // Red 255 Green -- Blue 0
      NEO01.setPixelColor(1, 255, int(84 - (pos)), 0);
      //
      // Title NeoPixel Color Cycle
      //
      // Red 255-0 Green 0-255
      NEO02.setPixelColor(0, int(255 - (pos*3)), int(pos*3), 0);
      // Blue 255-0 Red 0-255
      NEO02.setPixelColor(1, int(pos*3), 0, int(255 - pos*3));
    //
    // Second of three position groups 0-84
    } else if (pos < 170) {
      pos = pos - 85;
      //
      // BLUE LEDS
      if (pos % 2) {
        digitalWrite(LEDB02, HIGH);
        digitalWrite(LEDB04, LOW);
      } else {
        digitalWrite(LEDB02, LOW);
        digitalWrite(LEDB04, HIGH);
      }
      digitalWrite(LEDB01, HIGH);
      digitalWrite(LEDB03, HIGH);
      // WHITE LEDS
      digitalWrite(LEDW05, LOW);
      digitalWrite(LEDW06, LOW);
      //
      // RY PWM LEDS
      //
      // Start off and slowly get brighter to full on
      ledcWrite(LED31Bpwm, int(pos*3));
      ledcWrite(LED32Apwm, int(pos*3));
      ledcWrite(LED33Bpwm, int(pos*3));
      ledcWrite(LED34Apwm, int(pos*3));
      // Start on and slowly get dimmer to full off
      ledcWrite(LED31Apwm, int(255 - (pos*3)));
      ledcWrite(LED32Bpwm, int(255 - (pos*3)));
      ledcWrite(LED33Apwm, int(255 - (pos*3)));
      ledcWrite(LED34Bpwm, int(255 - (pos*3)));
      //
      // Flame NeoPixel Red=ON Green=Cycle Blue=OFF (R+G=Y)
      //
      // Red 255 Green ++ Blue 0
      NEO01.setPixelColor(1, 255, int(pos), 0);
      // Red 255 Green -- Blue 0
      NEO01.setPixelColor(0, 255, int(84 - (pos)), 0);
      //
      // Title NeoPixel Color Cycle
      //
      // Green 255-0 Blue 0-255
      NEO02.setPixelColor(0, 0, int(255 - (pos*3)), int(pos*3));
      // Red 255-0 Green 0-255
      NEO02.setPixelColor(1, int(255 - (pos*3)), int(pos*3), 0);
    //
    // Third of three position groups 0-84
    } else {
      pos = pos -170;
      //
      // BLUE LEDS
      digitalWrite(LEDB01, HIGH);
      digitalWrite(LEDB02, HIGH);
      digitalWrite(LEDB03, HIGH);
      digitalWrite(LEDB04, HIGH);
      //
      // Split third group for things that need even number of transitions
      if (pos <43) {
        // WHITE LEDS
        int wr05 = random(0,15);
        if (wr05 >9) { digitalWrite(LEDW05, HIGH); } else { digitalWrite(LEDW05, LOW); }
        int wr06 = random(0,15);
        if (wr06 >9) { digitalWrite(LEDW06, HIGH); } else { digitalWrite(LEDW06, LOW); }
        //
        // RY PWM LEDS
        //
        // Start off and slowly get brighter to full on
        ledcWrite(LED31Apwm, int(pos*6));
        ledcWrite(LED32Bpwm, int(pos*6));
        ledcWrite(LED33Apwm, int(pos*6));
        ledcWrite(LED34Bpwm, int(pos*6));
        // Start on and slowly get dimmer to full off
        ledcWrite(LED31Bpwm, int(255 - (pos*6)));
        ledcWrite(LED32Apwm, int(255 - (pos*6)));
        ledcWrite(LED33Bpwm, int(255 - (pos*6)));
        ledcWrite(LED34Apwm, int(255 - (pos*6)));
        //
        // Flame NeoPixel Red=ON Green=ON/OFF Blue=OFF (R+G=Y)
        //
        // Red 255 Green 25 Blue 0
        NEO01.setPixelColor(0, 255, 25, 0);
        // Red 255 Green 0 Blue 0
        NEO01.setPixelColor(1, 255, 0, 0);
      //
      // Split third group for things that need even number of transitions
      } else {
        // WHITE LEDS
        digitalWrite(LEDW05, LOW);
        digitalWrite(LEDW06, LOW);
        //
        // RY PWM LEDS
        //
        // Start off and slowly get brighter to full on
        ledcWrite(LED31Bpwm, int((pos-43)*6));
        ledcWrite(LED32Apwm, int((pos-43)*6));
        ledcWrite(LED33Bpwm, int((pos-43)*6));
        ledcWrite(LED34Apwm, int((pos-43)*6));
        // Start on and slowly get dimmer to full off
        ledcWrite(LED31Apwm, int(255 - ((pos-43)*6)));
        ledcWrite(LED32Bpwm, int(255 - ((pos-43)*6)));
        ledcWrite(LED33Apwm, int(255 - ((pos-43)*6)));
        ledcWrite(LED34Bpwm, int(255 - ((pos-43)*6)));
        //
        // Flame NeoPixel Red=ON Green=ON/OFF Blue=OFF (R+G=Y)
        //
        // Red 255 Green 25 Blue 0
        NEO01.setPixelColor(1, 255, 25, 0);
        // Red 255 Green 0 Blue 0
        NEO01.setPixelColor(0, 255, 0, 0);
      }
      //
      // Title NeoPixel Color Cycle
      //
      // Blue 255-0 Red 0-255
      NEO02.setPixelColor(0, int(pos*3), 0, int(255 - pos*3));
      // Green 255-0 Blue 0-255
      NEO02.setPixelColor(1, 0, int(255 - (pos*3)), int(pos*3));
    }    
    NEO01.show();
    NEO02.show();
    // Print current Iteration value to serial console for troubleshooting
    Serial.print(" Iteration=");
    Serial.print(i);
    Serial.print(" Position=");
    Serial.print(pos);
    //
    // TOUCH
    //
    //Read Touch Value
    TouchValue = touchRead(TouchPin);
    // Do Stuff If We Detect a Touch
    if (TouchValue < TouchThreshold) {
      // Print current Touch value/threshold to serial console for troubleshooting
      Serial.print(" TOUCHED=");
      Serial.print(TouchValue);
      Serial.print("/");
      Serial.print(TouchThreshold);
      //
      // LED BOOP EFFECT - OVERRIDES PRIOR LED SETTINGS BEFORE DELAY
      //
      // BLUE LEDS
      digitalWrite(LEDB01, HIGH);
      digitalWrite(LEDB02, HIGH);
      digitalWrite(LEDB03, HIGH);
      digitalWrite(LEDB04, HIGH);
      // WHITE LEDS
      digitalWrite(LEDW05, HIGH);
      digitalWrite(LEDW06, HIGH);
      // RY PWM LEDS
      ledcWrite(LED31Apwm, 255);
      ledcWrite(LED32Apwm, 255);
      ledcWrite(LED33Apwm, 255);
      ledcWrite(LED34Apwm, 255);
      ledcWrite(LED31Bpwm, 0);
      ledcWrite(LED32Bpwm, 0);
      ledcWrite(LED33Bpwm, 0);
      ledcWrite(LED34Bpwm, 0);
      // Flame NeoPixel
      NEO01.setPixelColor(0, 255, 84, 0);
      NEO01.setPixelColor(1, 255, 84, 0);
      NEO01.show();
      // Title NeoPixel
      NEO02.setPixelColor(0, 255, 255, 255);
      NEO02.setPixelColor(1, 255, 255, 255);
      NEO02.show();
    // Do Stuff If We DONT Detect a Touch
    } else {
      // Print current Touch value/threshold to serial console for troubleshooting
      Serial.print(" Touch=");
      Serial.print(TouchValue);
      Serial.print("/");
      Serial.print(TouchThreshold);
    }
    // Print Carriage Return
    Serial.println();
    // Pause the loop to display LEDS
    delay(DelayTime);
  }
}

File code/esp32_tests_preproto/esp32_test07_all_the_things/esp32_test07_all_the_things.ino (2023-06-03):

#include <Adafruit_NeoPixel.h>

// NeoPixel PIN VALUES
#define NEO01Pin 18   // 18 corresponds to GPIO18
#define NEO02Pin 19   // 18 corresponds to GPIO19

// LED PIN VALUES
#define LED01Pin 12  // 12 corresponds to GPIO12
#define LED02Pin 13  // 13 corresponds to GPIO13
#define LED03Pin 14
#define LED04Pin 27
#define LED05Pin 26
#define LED06Pin 25
#define LED07Pin 33
#define LED08Pin 32
#define LEDB1Pin 23
#define LEDB2Pin 22
#define LEDB3Pin 21
#define LEDB4Pin 5
#define LEDW1Pin 17
#define LEDW2Pin 16

// Touch PIN VALUE
#define TouchPin 4  // 4 corresponds to GPIO4 - Touch0

// PWM Properties
const int freq = 1000;
const int PWMChannel0 = 0;
const int PWMChannel1 = 1;
const int resolution = 8;

// Define NeoPixel Strips - (Num pixels, pin to send signals, pixel type, signal rate)
Adafruit_NeoPixel NEO01 = Adafruit_NeoPixel(2, NEO01Pin, NEO_RGB + NEO_KHZ800);
Adafruit_NeoPixel NEO02 = Adafruit_NeoPixel(2, NEO02Pin, NEO_RGB + NEO_KHZ800);

// Touch Properties
const int TouchThreshold = 20;
int TouchValue = 21;

// SETUP - RUN ONCE
void setup(){
  // configure LED PWM functionalitites per channel
  ledcSetup(PWMChannel0, freq, resolution);
  ledcSetup(PWMChannel1, freq, resolution);
  
  // attach the channel to the GPIO to be controlled
  ledcAttachPin(LED01Pin, PWMChannel0);
  ledcAttachPin(LED02Pin, PWMChannel1);
  ledcAttachPin(LED03Pin, PWMChannel0);
  ledcAttachPin(LED04Pin, PWMChannel1);
  ledcAttachPin(LED05Pin, PWMChannel0);
  ledcAttachPin(LED06Pin, PWMChannel1);
  ledcAttachPin(LED07Pin, PWMChannel0);
  ledcAttachPin(LED08Pin, PWMChannel1);

  //Normal LED output
  pinMode(LEDB1Pin, OUTPUT);
  pinMode(LEDB2Pin, OUTPUT);
  pinMode(LEDB3Pin, OUTPUT);
  pinMode(LEDB4Pin, OUTPUT);
  pinMode(LEDW1Pin, OUTPUT);
  pinMode(LEDW2Pin, OUTPUT);

  // Initializes the NeoPixels
  NEO01.begin();
  NEO02.begin(); 

  // Set Neopixel Brightness (0-255 scale)
  NEO01.setBrightness(200);
  NEO02.setBrightness(200);

  // setup the serial output baud rate
  Serial.begin(115200);
}

// LOOP - MAIN 
void loop(){
  // Set Delay Time [in ms]
  int DelayTime = 10;
  digitalWrite(LEDB1Pin, HIGH);
  digitalWrite(LEDB2Pin, HIGH);
  digitalWrite(LEDB3Pin, HIGH);
  digitalWrite(LEDB4Pin, HIGH);
  digitalWrite(LEDW1Pin, HIGH);
  digitalWrite(LEDW2Pin, HIGH);

  // Iterate 0 to 255
  for(int i=0; i<256; i++){

    // Set position value to iteration
    int pos = i;
    if (pos < 85) {
      // Start off and slowly get brighter to full on
      ledcWrite(PWMChannel0, int(pos*3));
      // Start on and slowly get dimmer to full off
      ledcWrite(PWMChannel1, int(255 - (pos*3)));
      //
      // NeoPixel Color Cycle
      //
      // Red 255-0 Green 0-255
      NEO01.setPixelColor(0, int(255 - (pos*3)), int(pos*3), 0);
      NEO02.setPixelColor(1, int(255 - (pos*3)), int(pos*3), 0);
      // Green 255-0 Blue 0-255
      NEO01.setPixelColor(1, 0, int(255 - (pos*3)), int(pos*3));
      // Blue 255-0 Red 0-255
      NEO02.setPixelColor(0, int(pos*3), 0, int(255 - pos*3));
    } else if (pos < 170) {
      pos = pos - 85;
      // Start off and slowly get brighter to full on
      ledcWrite(PWMChannel1, int(pos*3));
      // Start on and slowly get dimmer to full off
      ledcWrite(PWMChannel0, int(255 - (pos*3)));
      //
      // NeoPixel Color Cycle
      //
      // Red 255-0 Green 0-255
      NEO02.setPixelColor(0, int(255 - (pos*3)), int(pos*3), 0);
      // Green 255-0 Blue 0-255
      NEO01.setPixelColor(0, 0, int(255 - (pos*3)), int(pos*3));
      NEO02.setPixelColor(1, 0, int(255 - (pos*3)), int(pos*3));
      // Blue 255-0 Red 0-255
      NEO01.setPixelColor(1, int(pos*3), 0, int(255 - pos*3));
    } else {
      pos = pos -170;
      if (pos <43) {
        // Start off and slowly get brighter to full on
        ledcWrite(PWMChannel0, int(pos*6));
        // Start on and slowly get dimmer to full off
        ledcWrite(PWMChannel1, int(255 - (pos*6)));        
      } else {
        // Start off and slowly get brighter to full on
        ledcWrite(PWMChannel1, int((pos-43)*6));
        // Start on and slowly get dimmer to full off
        ledcWrite(PWMChannel0, int(255 - ((pos-43)*6)));
      }
      //
      // NeoPixel Color Cycle
      //
      // Red 255-0 Green 0-255
      NEO01.setPixelColor(1, int(255 - (pos*3)), int(pos*3), 0);
      // Green 255-0 Blue 0-255
      NEO02.setPixelColor(0, 0, int(255 - (pos*3)), int(pos*3));
      // Blue 255-0 Red 0-255
      NEO01.setPixelColor(0, int(pos*3), 0, int(255 - pos*3));
      NEO02.setPixelColor(1, int(pos*3), 0, int(255 - pos*3));
    }    
    NEO01.show();
    NEO02.show();
    // Print current Iteration value to serial console for troubleshooting
    Serial.print(" Iteration=");
    Serial.print(i);
    Serial.print(" Position=");
    Serial.print(pos);
    // TOUCH
    TouchValue = touchRead(TouchPin);
    // Print current Touch value to serial console for troubleshooting
    if (TouchValue < TouchThreshold) { Serial.print(" TOUCHED="); } else { Serial.print(" Touch="); }
    Serial.print(TouchValue);
    // Print Carriage Return
    Serial.println();
    // Pause the loop to display LEDS
    delay(DelayTime);
  }
}

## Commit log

2023-04-15 initial eda template added
    [BatteryHolder_2466_1xAAA.step, BatteryHolder_2468_2xAAA.step, Battery_Holder_3xAAA_Simple.step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]
2023-04-28 schematic start
    [future_badge.kicad_sch]
2023-05-12 more stuff
    [future_badge.kicad_sch]
2023-05-17 more test code and esp32 sch and fp and 3d
    [future_badge.kicad_sch]
2023-05-19 updated schematic
    [future_badge.kicad_pcb, future_badge.kicad_sch]
2023-05-31 schematic and code and art updates
    [future_badge.kicad_pcb, future_badge.kicad_sch]
2023-06-03 art and footprint and pcb updates
    [future_badge.kicad_pcb, future_badge_art-2-edgecuts-7-2.dxf, future_badge_art-2-frontmask-flames-7-2.dxf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]
2023-06-05 PCB layout
    [PinSocket_1x03_P2.54mm_Horizontal.step, PinSocket_1x03_P2.54mm_Vertical.step, PinSocket_1x04_P2.54mm_Horizontal.step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]
2023-06-06 prototype ordered
    [future_badge-B_Cu.gbl, future_badge-B_Mask.gbs, future_badge-B_Paste.gbp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]
2023-06-17 prototype code and images
2023-06-19 pcb updates
    [future_badge.kicad_pcb]
2023-06-21 true edits for voltreg and cleanup
    [CUI_PXO7803-500-M-TR.step, future_badge.kicad_sch]
2023-06-23 incorporate updates from true
    [CUI_PXO7803-500-M-TR.step, future_badge.kicad_sch]
2023-06-26 pcb rev2 complete
    [future_badge-B_Cu.gbl, future_badge-B_Mask.gbs, future_badge-B_Paste.gbp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]
2023-07-07 arduino cli configs and script

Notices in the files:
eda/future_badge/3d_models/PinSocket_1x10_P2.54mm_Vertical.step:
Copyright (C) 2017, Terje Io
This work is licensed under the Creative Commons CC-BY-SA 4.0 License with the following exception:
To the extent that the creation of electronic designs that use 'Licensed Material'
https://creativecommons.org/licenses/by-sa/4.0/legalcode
